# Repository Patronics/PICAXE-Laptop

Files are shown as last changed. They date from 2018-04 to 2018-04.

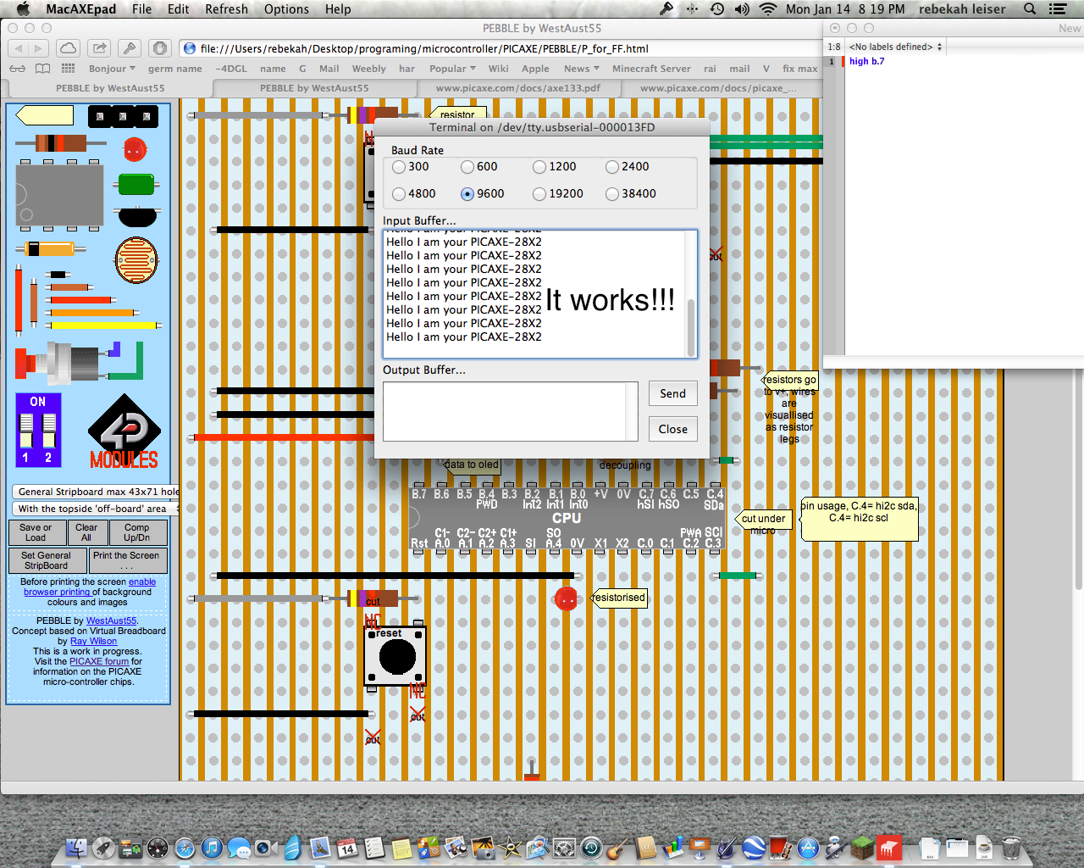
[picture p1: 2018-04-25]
laptop project/report/screenshots/It works!!.png

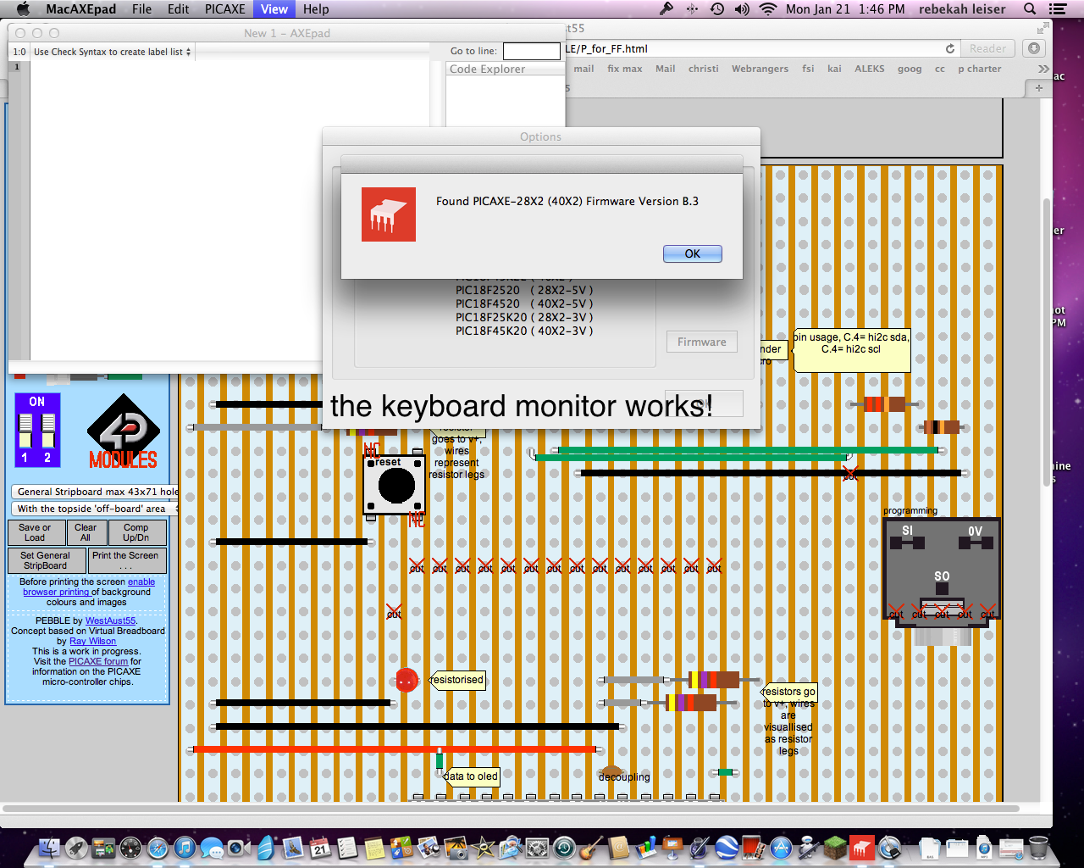
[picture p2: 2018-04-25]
laptop project/report/screenshots/keyboard monitor works!.png

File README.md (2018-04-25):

# PICAXE_Laptop
A PICAXE microcontroller based laptop with a text editor, calculator, timer, and more!

This is a project I made for the Sacramento Regional Science Fair and California State Science Fair in 2013. It won first prize in the regional science fair and 4th in the state science fair.

You can read more about it at my website: http://www.patronics.org/picaxe-computer.html

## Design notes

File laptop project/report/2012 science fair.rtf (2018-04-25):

ideas
Low voltage operating chip "watchdog" to shut down at low voltages (could use low voltage 3 volt 28x2)
later comments: I used calibadc to read the voltage on startup and warn the user if the voltage is too low.
non IBM PC compatible no IBM PC compatible parts (completely original)
hi2cout to enable i²c for keyboard, storage, ect. i2c is an alternative for PCI/PCIe found in most computers. Iimproved efficiency due to using i²c function built into the hardware as opposed doing it with software (bit banging).
light/distance sensor to detect closing of case
switch with transistors to disable all non programming pins (for programming)
use indicator LED's
use multiple slots of 28x2 cpu to have up to four operating systems e.g. sd card; non-sd card functions; one reserved for future use; one for diagnostic purposes.
clear case so people can see internal electronics
organize the files on the computer in a hierarchical file system rather than a sinjgle level file system you may then organize files by their purpose or type e.g. system, data, logs, etc.

Log
12/24/12 worked on basic microcontroller requirements (programming and power)
Setting up hardware hi2c out to enable i2c (for keyboard, storage, etc.)
Planned and added switch to reset pin with resistor. Added pull-up resistor.
12/26 Need SD card reader/writer to improve capacity to potentially allow communication between my laptop and other computers
12/28 Trying to find plain file editor (not plain text)
1/5 reading manual for alfat and card reader board, needs 3.3 volts so will need to have a voltage regulator from 4.5 to 3.3 volts.
later comments: instead of using a voltage regulator I used 3 batteries in series with the contacts of each acsesable I got 3 volts directly for 2 of the batteries for the alfat board.
Since you can't choose and edit any part of a file when you choose a file it will load it into RAM (possible external FRAM and after the edits have been made give options to save the file or discard the changes.
I am using the sd card reader for all data storage so do not need the FRAM.
1/12 soldered connections for power and programming for both CPU and keyboard.
1/14 continued to solder basic connections, then tested followed by debugging for two plus hours. Wrote test program to blink LED from main processor.
1/18 - 2.5 battery case wires broke so replaced with 3 individual AA battery boxes on separate stripboard for increased durability and selectable voltage of 1.5,3, and 4.5 volts. Debugged and successfully fixed (there was a problem with the programming connector) the PICAXE 2.8X2 keyboard processor. Added keyboard connector and successfully got keyboard. I wrote and tested a program allowing the keyboard processor to sent keyboard data to the main processor.
1/20 - 2/1 Constructed case.
2/2 connected screen. Did several tests/demo programs. Display all possible characters on
screen; display characters, number and symbol for character typed on keyboard. Display typed symbols on screen sequentially in text editor fashion. (like Pages, Word, etc.) Changed decoding code to display correct symbols. Entered key identifying function into keyboard controller to free up processsing of CPU
.2/4 decreased code size from 1064 bytes to 832 with optimization of menu structure.
2/7 Added functionality for sleep mode in both CPU and keyboard with keyboard waking up CPU when wake up key pressed on keyboard. Drilled holes on case to allow for external programming while in case.
2/8 Added circuit for sd card reader; successfully interfaced with sd card reader and received its version number through i²c (as a basic test of whether it could read it or not)
2/09 Created filoe hello world.txt, successfully read it from sd card reader; I set sd card reader to read 80 characters (the size of the display) with spaces for any unused characters instead of being the exact number of characters on the document.
2/10 Organized files on in a hierarchical file system rather than a single level file system.
2/11 SD read: the sd read routine reads one page of the file and allows it to create a shortcut from the menu or input it with typing (or any other way I program )instead of having a separate program everytime you need to read a fie.
2/12 The sd writing program occasionally frooze. Set it to Sertxd (send data to computer) to see where a program froze. I identified that the keyboard uc was functioning properly since kb still blinked LED's and when I set main uc to Sertxd the value from the keyboard lead it would return proper value and would not return any value if it was frozen.
I added method to go to any file on the drive with file path. Writing code for ad rad set up. Theoretically I could put any file on it and it would read it.
2/16 When I was debugging

2/18 Added capitalization by programming the keyboard monitor so when shift key is pressed a bit variable called shift is set to equal one and when this variable is set to one the microcontroller reads the value of the key to convert it to the correct character from its internal storage (called EEPROM) and then sets the variable shift to zero. It functions similarly to an iPhone when shift is pressed the next key is capitalized and then goes back touncapitalized. It functions similarly to caplock but toggles the bit each time cap lock is pressed.
2/19 I modified the file listing function to display files in an easy to read format, showing the ``````````````````````file name,it's attributes( e.g. read only, hidden, etc.), and the file's size.
The sd read reoutine reads one page worth of the file ande allows it to create a shortcut from the nmenu or input it with typing (or any other way I program) instead of having a separate program everytime you need to read a file.
I added function to read the power supply voltage (battery level) using the calib adc command and some math. I am now able to read the voltage with 100 milliamp resolution without a multimeter ( no longer need to open case to test batteries).
2/20 added function to check power supply on start up and warn if it was low. Fixed code to remove unnecessary characters from sd card reads. Worked on single character sd card reads allowing for enter, tab, etc.
2/21 Working on making the program execution by over-clocking the frequency to 16 Mhz instead of the default 8 Mhz. Need to change the commands that require specific timing such as pause, hhitc set up, serout. I realized I only have to use some symbol that will be assigned a different value depending on thefrequency defined. I can't set fequency higher though I could use an external resonater pf up to 6hz. Serial communication speed for screen would be too fast. I am not working on this now as the screen seemed to be unable to keep up with the cpu, in the future I will try to overclock the screen so it can keep up.
I added function to save contents of the display when using word edit, when a user presses print screen on the keyboard. Now it is possible to write to the sd card.
2/24 In word edit I added a function to support tab key.

List of supplies:
serial 20x4 OLED display $30.00 (cheap alternative serial LCD: $9.00)
picaxe 28X2 microcontroller (2) $6.80 ea.
plain stripboards (perfboard) (3 - 4) $1.50 ea.
single AA battery holder (3) $1.09 ea.
Alfat SD card reader $44.95
resistors (22k (2), 10k (2), 4.7k (2) negligible ($10.00 for 500 pieces)
various wires (negligible)
ps2 keyboard $5.00
ps2 stripboard adaptor $.95
power switch $1.00
sd card (up to 32 GB) (lower capacity acceptable) $6.95 for 2 GB $15.00 for 16 GB
programming adaptor (headphone jack) $.10

Optional Supplies:
decoupling capacitors(3) (highly recommended) $0.10
ethernet cable/adaptor (communication between top and bottom halves of laptop) (use wires if not using this) ( free sample from molex.com)
indicator LEDs (2) $.09 ea,
case (material of your choice eg. wood/plastic) $10.00 and up
200 ohm resistors (for indicator LEDs) (2) negligible
extension cable (to program without opening case) $0.97

entry level: $89.10
full version: $129.26

Procedure
Ordered componets
Constructed case from plastic sheets and blocks.
Draw a stripboard diagram using PEBBLE (PICAXE Electronic BreadBoard Emulator)
Solder the PICAXE microcontrollers and programming connectors and tested circuit, with program to blink an LED, hardware was not found. After several tests I discovered that the programming connectors made an intermittant connection and needed resoldering.
Solder the data and clock lines of the i²c bus connecting the PICAXE 28 x2 CPU and the 2 x2 keyboard monitor.
Soldered keyboard adaptor, first keyboard didn't work so ordered another as a replacement. The native ps2 keyboard from our old computer works.
Battery cables broke so decided to make a more durable and efficient power supply.

conclusion notes
SD card related operating system functions: read from sd card, read files on sd card, write to sd card,
I have the idea to allow background programs/processes. e.g. timer, etc. by designating some variables for background processing separately from the active program varibles (RAM)

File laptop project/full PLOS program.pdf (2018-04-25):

1 | picaxe laptop demo program slot 0 | 'by Patrick Leiser
2 | #picaxe 28x2
3 | #slot 0
4 | #revision 2
5 | 'pinout
6 | ' | _________
7 | ' | reset | rst B.7 | LED (red)
8 | ' | | A.0 B.6| Speakers
9 | ' | | A.1 B.5|
10 | ' | | A.2 B.4|
11 | ' | | A.3 B.3|
12 | ' | serin |serin B.2| keyboard wakeup (currently unused)
13 | ' | serout |A.4 B.1|
14 | ' | 0V | 0V B.0|
15 | ' | | res +V| +5V
16 | ' | | res 0V | | 0V
17 | ' SD card busy | C.0 C.7|
18 | ' OLED serout | C.1 C.6|
19 | ' | | C.2 C.5|
20 | ' | hi2c | C.3 C.4| hi2c (keyboard and SD card)
21 | ' | _________
22 | #define 8mhz | 'clock frequency is 8mhz
23 | '#define 16mhz | 'too fast for display, overclock display to 32 Mhz?
24 | #ifdef 8mhz
25 | setfreq m8 | 'set clock frequency to 8MHz
26 | symbol screenspeed=N2400_8 | 'N2400 at 8 MHz
27 | symbol i2cspeed=i2cfast_8 | 'i2c 400khz at 8 MHz
28 | #endif
29 | #ifdef 16mhz
30 | setfreq m16 | 'set clock frequency to 16 MHz
31 | symbol screenspeed=N2400_16 | 'N2400 at 16 MHz
32 | symbol i2cspeed=i2cfast_16 | 'i2c 400khz at 16 MHz
33 | #endif
34 | 'i2c constants
35 | symbol alfat=%10100100 | 'sd card reader
36 | symbol keyboard=%01010100 | 'keyboard reading PICAXE 28X2
37 | 'system variables
38 | symbol screenlevel=bit0 | 'unused scrolling function
39 | symbol tempbit1 =bit1 | 'temporary bit 1
40 | symbol tempbit2=bit2 | 'tempoary bit 2
41 | symbol loopcount=b11 | ' number of loops in for...next loops
42 | symbol menupage=b21 | 'which page of menu you are on
43 | 'keyboard variables
44 | symbol keycheck = b4 | 'will be one when data is valid, otherwise 0 or 255
45 | symbol keyraw =b5 | 'data direcly from keyboard
46 | symbol keyascii = b6 | 'data from keyboard converted to ASCII
47 | symbol keynum = b7 | ' value of number keys 0-9
48 | 'wordedit variables
49 | symbol cursorrow = b8 | 'part of row in wordedit
50 | symbol cursorcol = b9 | 'part of colum in wordedit
51 | symbol cursorpos = b10 | 'cursor position for OLED
52 | '
53 | symbol temp1=b14 | 'temporary byte (8 bits)1
54 | symbol temp2=b15 | 'tempoaray byte 2
55 | symbol tempw1=w7 | 'tempoary word (16 bits) 1 (overlaps temp1 and temp2)
56 | symbol temp3=b16 | 'tempoary byte 3
57 | symbol temp4=b17 | 'tempoary byte 4
58 | symbol tempw2=w8 | 'tempoary word 2 | (overlaps temp3 and temp4
59 | symbol temp5=b18 | 'tempoary byte 5
60 | symbol temp6=b19 | 'tempoary byte 6
61 | symbol tempw3=w9 | 'tempoary word 3 | (overlaps temp5 and temp6

62 | symbol charremove=b20 | 'amount of sd card data to remove eg !00
63 | 'symbol charremove1=b24 | 'single character to remove eg !
64 | symbol pointertrack=w11 | 'track pointer read loops
65 | symbol first=b24
66 | symbol second=b25
67 | 'game variables
68 | 'symbol guesscount = b11
69 | 'symbol hitcount = b0
70 | 'symbol gamerandom = b12
71 | 'symbol gamerandom2 =b13
72 | 'symbol gamerandom3 =b14
73 | 'symbol gamerandom4 =b15
74 | 'symbol gamerandom5 =b16
75 | 'symbol gamerandom6 =b17
76 | 'symbol gamerandom7 =b18
77 | 'symbol gamerandom8 =b19
78
79
80 | 'math variables
81 | 'symbol math1=w3 'b4/b5
82 | 'symbol mathone=w3 'b4/b5
83 | 'symbol math2=w4 'b6/b7
84 | 'symbol mathtwo=w4 'b6/b7
85 | 'symbol mathresult=w6'b8/b9
86 | 'startup
87
88
89 | if pinC.4=0 then | ' if i2c read/write in progress
90 | for loopcount = 0 to 15
91 | toggle C.3 | 'clear i2c bus read/write
92 | pause 30
93 | if pinC.4=1 then exit
94 | next loopcount
95 | endif
96 | hi2csetup i2cmaster,alfat,i2cspeed,i2cbyte | 'setup i2c comunication for SD card reader
97 | 'pause 200
98 | hi2cout ("I M:",lf) | 'initalise sd card
99
100 | setup:
101 | hi2cin (b12)
102 | if b12=255 then setup2
103 | if b12 <> "!" then setup
104 | hi2cin (b12,b12,b12)
105
106 | hi2cout ("I M:",lf)
107 | setup2:
108 | #ifdef 8mhz
109 | 'pause 600
110 | tune B.6,4,($40,$42,$44,$45,$47,$02,$49) | 'startup chime
111 | #endif
112 | #ifdef 16mhz
113 | tune B.6,8,($40,$42,$44,$45,$47,$02,$49) | 'startup chime
114 | #endif
115 | serout C.1, screenspeed, (254,128,254,1)'clear display
116
117 | 'read voltage
118 | 'CalibAdc10 tempw1 | 'read voltage of internal fixed voltage reference
119 | gosub getvolts
120 | 'tempw1 = 10476 / tempw1 | 'convert to volts
121 | if tempw1<38 then
122 | gosub powerdisplay

123 | sound B.6, (50,50,100,50)
124 | gosub getakey
125 | endif
126 | #ifdef 8mhz
127 | pause 30 | 'pause 30 ms
128 | #endif
129 | #ifdef 16mhz
130 | pause 70
131 | #endif
132
133 | '''''''''''''''''''''''''''''''''''''''''''''''''''''''''''''''''''''''''''''''''''''''''''''''''''''''''''''''
134 | 'menus
135 | main:
136 | 'clearvar:
137 | 'for bptr=5 to 255
138 | ' | @bptr=0
139 | 'next bptr
140 | menu: | 'main menu
141 | serout C.1,screenspeed, (254,128,254,1) | 'clear display
142 | pause 30
143 | select case menupage 'select page
144 | case 0 'first page
serout C.1,screenspeed, ("1 Utilities",254,192,"2 Tests",254,148,"3 SD card",254,212,"4 favorites ",180) 'menu display

145

146 'serout C.1,N2400,(254,192,"2 Tests") 147
148 | 'serout C.1,N2400,(254,148,"3 SD card")
149 | 'serout C.1,N2400,(254,148,"3 games")
150 | 'serout C.1,N2400, (254,212,"4 favorites ",180)
151 | 'serout C.1,N2400, (254,212,"4 other")
152 | 'serout C.1,N2400,(254,212,"4 calculator")
153 | case 1 '2nd page
154 | serout C.1,screenspeed,("5 other")
155 | else
156 | menupage=0
157 | goto menu
158 | endselect
159 | gosub getakey
branch keynum, (menu,utilitymenu, testmenu,gamemenu,favoritesmenu,othermenu) | 'go to menu item
selected by key on keyboard

160

161 | 'if keynum = 10 then
162 | select case keyraw | 'shortcut keys
163 | case 29 | 'w
164 | goto wordeditsetup
165 | case 45 | 'r
166 | goto sdreadsetup
167 | case 75 | 'l
168 | goto sdinitalizelist
169 | case 33 | 'c
170 | goto calculatorsetup
171 | endselect
172 | 'endif
173 | if keyraw=90 or keyraw= 114 then
174 | inc menupage
175 | elseif keyraw=102 or keyraw=117 then
176 | dec menupage
177 | endif
178 | goto menu
179
180 | utilitymenu: | 'utility menu
181 | serout C.1,screenspeed, (254,128)

serout C.1, screenspeed, (254,1)
pause 30
serout C.1,screenspeed, ("1 Wordedit") serout C.1,N2400,(254,192,"2 calculator") 'serout C.1,N2400,(254,148,"3 ")

'serout C.1,N2400,(254,212,"4 ")

gosub getakey
branch keynum,(menu,wordeditsetup,calculatorsetup)

if keyraw= 118 or keyraw=108 then menu
goto utilitymenu
197 | testmenu: | 'test menu
serout C.1,screenspeed, (254,128)
serout C.1, screenspeed, (254,1)
| pause 30
serout C.1,screenspeed, ("1 list characters")
serout C.1,screenspeed,(254,192,"2 Keyboard to screen") serout C.1,screenspeed,(254,148,"3 read power supply") serout C.1,screenspeed,(254,212,"4 System info") 'serout C.1,N2400, (254,212,"4 SD card read")
'serout C.1,N2400,(254,212,"4 calculator")
| gosub getakey
branch keynum,(menu,listcharacters,keyboardtoscreen,readpower,sysinfo)',gettime)

if keyraw=118 or keyraw=108 then menu
| goto testmenu sdmenu:

gamemenu: 'sd card menu, used to be game menu
| 'run 1
serout C.1,N2400, (254,128,254,1)
select case menupage
| case 0
serout C.1, screenspeed, ("1 read sdcard")
serout C.1, screenspeed, (254,192,"2 about PLOS")
serout C.1, screenspeed, (254,148,"3 add to visitor log") serout C.1, screenspeed, (254,212,"4 view visitor log ",180) 'serout C.1,N2400, ("no games, press esc")
'serout C.1,N2400,(254,192,"- subtraction")
'serout C.1,N2400,(254,148,"* multiplication")
'serout C.1,N2400,(254,212,"/ division")
| case 1
serout C.1, screenspeed, ("5 list sd files") serout C.1, screenspeed, (254,192,"6 tutorial")
| else
menupage=0
goto gamemenu
| endselect gosub getakey branch keynum,

(menu,sdreadsetup,sdaboutsetup,visitorlogappend,visitorlogreadsetup,sdinitalizelist,tutorialsetup) if keyraw =118 or keyraw=108 then menu
if keyraw=90 or keyraw= 114 then
inc menupage
elseif keyraw=102 or keyraw= 117 then

242 | dec menupage
243 | endif
244
245 goto sdmenu
246
247 | favoritesmenu: | 'shortcuts to sd card files ect menu
248 | serout C.1,screenspeed, (254,128,254,1)
249 | pause 30
250 | serout C.1,screenspeed, ("1 ")
251
252 | gosub getakey
253 | branch keynum, (menu)
254
255 | if keyraw = 118 or keyraw =108 then menu
256 | goto favoritesmenu
257
258 | othermenu:
259 | serout C.1,screenspeed, (254,128)
260 | serout C.1, screenspeed, (254,1)
261 | pause 30
262 | serout C.1,screenspeed, ("1 star animation")
263
264 | gosub getakey
265 | branch keynum, (menu,staranimatesetup)
266
267 | if keyraw = 118 or keyraw =108 then menu
268 | goto othermenu
269 | ''''''''''''''''''''''''''''''''''''''''''''''''''''''''''''''''''''''''''''''''''''''''''''''''''''''''''''''
270 | 'sub program 1: wordedit
271 | 'a text editor like pages or word
272 | wordeditsetup:
273 | serout C.1, screenspeed, (254,14,254,128,254,1) 'cursor on, top of display, clear display
274 | pause 30
275 | cursorrow=0 | 'top of display
276 | cursorcol=0 | 'top of display
277 | wordedit:
278 | gosub getakey | 'get a key from keyboard
279
280 | select case keyraw | 'select raw key value
281 | case 118 | 'esc
282 | goto menu
283 | case 108 | 'home
284 | cursorrow=255
285 | cursorcol=0
286 | case 90 | 'enter
287 | cursorrow = 21
288 | case 102 | 'backspace
289 | if cursorrow = 0 then
290 | dec cursorcol
291 | cursorrow = 20
292 | endif
293 | cursorrow=cursorrow-1
294 | gosub position
295 | cursorrow=cursorrow-1
296 | serout C.1,screenspeed, (" ")
297 | case 13 | 'tab
298 | cursorrow=cursorrow+2
299 | serout C.1, screenspeed, (" ")
300 | @bptrinc=9 | 'tab
301 | @ptrinc=9
302 | @bptrinc=0 | 'null

303 | @bptr=0 | 'null
304 | case 107 | 'left arrow
305 | if cursorrow = 0 then
306 | dec cursorcol
307 | cursorrow = 20
308 | endif
309 | cursorrow=cursorrow - 2
310 | case 116 | 'right arrow
311 | case 114 | 'down arrow
312 | inc cursorcol
313 | dec cursorrow
314 | case 117 | 'up arrow
315 | dec cursorcol
316 | dec cursorrow
317 | case 124
318 | serout C.1, screenspeed, (254,128,"print screen")
319 | goto printscreen
320 | else
321 | serout C.1,screenspeed, (keyascii)
322 | @bptr=keyascii | 'store contents of the screen for ability to save
323 | @ptrinc=keyascii | 'store contents of the screen for abbility to save in progress
324 | endselect
325
326 | inc cursorrow
327 | gosub position
328 | goto wordedit
329 | position: | 'update position of cursor
330 | if cursorrow >19 then
331 | inc cursorcol
332 | cursorrow=0
333 | endif
334 | select case cursorcol
335 | case 1
336 | cursorpos=192
337 | 'serout C.1, N2400, (254, 192)
338 | 'serout C.1, N2400, ("ln 1")
339 | case 2
340 | cursorpos=148
341 | 'serout C.1, N2400, (254, 148)
342 | 'serout C.1,N2400,("ln 2")
343 | case 3
344 | cursorpos=212
345 | 'serout C.1,N2400, (254,212)
346 | 'serout C.1, n2400,("ln 4")
347 | else
348 | cursorpos=128
349 | 'serout C.1,N2400,(254,128)
350 | 'serout C.1,N2400,("ln 0")
351 | cursorcol=0
352 | endselect
353 | cursorpos = cursorrow+cursorpos
354 | bptr=cursorpos
355 | serout C.1, screenspeed, (254,cursorpos)
356 | return
357 | goto wordedit
358
359
360 | printscreen: ' save the contents of the screen to SD card
361 | hi2cout [alfat],("O 1A>M:\\screenshots",92) '92=\ | \\=\
362 | serout C.1, screenspeed, (254,128,"name (not full path)")
363 | gosub sdout

364 pointertrack= ptr
365
366 | first = pointertrack / 16 + "0" | '4 msb plus ascii "0"
367 | If first > "9" Then | 'if more than "9"
368 | first = first + 7 | 'add seven (starting "A","B",etc
369 | EndIf
370
371 | second = pointertrack & $0F + "0"
372 | If second > "9" Then
373 | second = second + 7
374 | EndIf
375 | hi2cout ("W 1>",first,second,lf) 'write handle 1, pointertrack characters,
376 | sertxd (#pointertrack)
377 | hi2cin (b12,b12,b12,b12)
378 | for ptr=0 to pointertrack
379
380
381 | hi2cout (@ptr)
382 | sertxd (@ptr,#ptr)
383 | for loopcount = 0 to 14
384 | hi2cin (b12)
385 | next loopcount
386 | next ptr
387 | 'for bptr=128 to 147 | 'line 1
388 | ' | hi2cout ("W 1>1",lf) 'write handle 1, one character,
389 | ' | hi2cin (b12)
390 | ' | serout C.1,screenspeed, (b12)
391 | ' | hi2cin (b12)
392 | ' | serout C.1,screenspeed, (b12)
393 | ' | hi2cin (b12)
394 | ' | serout C.1,screenspeed, (b12)
395 | ' | hi2cin (b12)
396 | ' | serout C.1,screenspeed, (b12)
397 | ' | hi2cout(@bptr)
398 | ' | for loopcount = 0 to 14
399 | ' | hi2cin (b12)
400 | ' | next loopcount
401 | 'next bptr
402 | 'for bptr=192 to 211 | 'line 2
403 | ' | hi2cout ("W 1>1",lf)
404 | ' | hi2cin (b12,b12,b12,b12)
405 | ' | hi2cout(@bptr)
406 | ' | for loopcount = 0 to 14
407 | ' | hi2cin (b12)
408 | ' | next loopcount
409 | 'next bptr
410 | 'for bptr=148 to 167 | 'line 3
411 | ' | hi2cout ("W 1>1",lf)
412 | ' | hi2cin (b12,b12,b12,b12)
413 | ' | hi2cout(@bptr)
414 | ' | for loopcount = 0 to 14
415 | ' | hi2cin (b12)
416 | ' | next loopcount
417 | 'next bptr
418 | 'for bptr=212 to 241 | 'line 4
419 | '' | hi2cout ("W 1>1",lf)
420 | ' | hi2cin (b12,b12,b12,b12)
421 | ' | hi2cout(@bptr)
422 | ' | for loopcount = 0 to 14
423 | ' | hi2cin (b12)
424 | ' | next loopcount

425 'next bptr
426
427 | hi2cout ("C 1",lf)
428 | hi2cout ("C 1",lf)
429 | hi2cin (b12,b12,b12,b12)
430
431 | serout C.1, screenspeed, (254,128,"complete")
432 | gosub getakey
433 | goto wordeditsetup
434 | ''''''''''''''''''''''''''''''''''''''''''''''''''''''''''''''''''''''''''''''''''''''''''''''''''''''''''''''''''''''''''
435 | 'sub program 2: keyboard to screen
436 | keyboardtoscreen: | 'show information about key on screen
437 | gosub getakey 'read a key
438 | serout C.1,screenspeed, (254,128,254,1) 'clear screen
439 | serout C.1,screenspeed, (#keyraw," ",keyascii," ",#keyascii," ",#keynum) 'display information about key
440 | if keyraw = 118 then 'if escape
441 | #ifdef 8mhz
442 | pause 1000 | 'pause a second
443 | #endif
444 | #ifdef 16mhz
445 | pause 2000 | '1 sec
446 | #endif
447 | goto menu | 'go to menu
448 | endif
449 | goto keyboardtoscreen 'loop
450
451 | '''''''''''''''''''''''''''''''''''''''''''''''''''''''''''''''''''''''''''''''''''''''''''''''''''''''''''''''''''''''''''
452 | 'sub program 3: list characters
453 | listcharacters: | 'list caracters avaiable for display
454 | serout C.1,screenspeed,(254,128) ; move to start of first line
455 | for b0 = 0 to 252 | 'all characters, no commands
456 | serout C.1,screenspeed,(b0," ") 'display character and space
457 | inc cursorrow 'next position on display
458 | gosub position
459 | gosub checkforkey 'check if esc has been pressed
460 | if keyraw= 118 then menu
461 | next b0
462
463 goto listcharacters
464
465 | 'gettime: 'unused routine to retrive time
466 | 'serout C.1, screenspeed, (254,128,254,1)
467 | 'pause 30
468 | 'hi2cout ("G D",lf)
469 | 'for loopcount =0 to 11
470 | ' | hi2cin (b12)
471 | ' | serout C.1, screenspeed, (b12)
472 | 'next loopcount
473 | 'serout C.1, screenspeed, (254,192)
474 | 'hi2cout ("G T",lf)
475 | 'for loopcount =0 to 8
476 | ' | hi2cin (b12)
477 | ' | serout C.1, screenspeed, (b12)
478 | 'next loopcount
479 | 'gosub getakey
480 | 'goto menu
481 | 'settime:
482 | 'hi2cout ("T B",lf)
483 | 'hi2cin (b12,b12,b12,b12)
484 | 'pause 200
485 | 'hi2cout ("S 42566DA0",lf)

486 | 'hi2cin (b12,b12,b12,b12)
487 | 'goto menu
488 | '''''''''''''''''''''''''''''''''''''''''''''''''''''''''''''''''''''''''''''''''''''''''''''''''''''''''''''''''''''''''
489 | 'voltage reader
490 | readpower:
491 | serout C.1,screenspeed, (254,128,254,1) 'clear display
492 | pause 30
493 | gosub getvolts
494 | gosub powerdisplay
495 | gosub getakey
496 | goto main
497 | getvolts:
498 | CalibAdc10 tempw1
499 | tempw1 = 10476 / tempw1
500 | bintoascii tempw1,temp3,temp3,temp4 | 'lower byte of temp w1
501 | return
502 | powerdisplay:
503 | 'tempw1 = 52377 /tempw1 * 2
504 | 'serout C.1,screenspeed, (#tempw1)
505 | serout C.1, screenspeed, ("power=",temp3,".",temp4," V")
506 | serout C.1, screenspeed, (254,192,"full charge=4.5 V")
507 | return
508 | 'gosub getakey
509 | 'goto main
510 | '''''''''''''''''''''''''''''''''''''''''''''''''''''''''''''''''''''''''''''''''''''''''''''''''''''''''''''''''''''''
511 | sdaboutsetup:
512 | pause 30
513 | hi2cout [alfat],("O 0R>M:\\system\\about.txt",lf) | '\\= \
514 | goto presdread
515
516 | sdreadsetup: | 'read file at path indicated
517 | serout C.1, screenspeed, (254,1) | 'clear display
518 | pause 30 | 'wait for display to clear
519 | serout C.1, screenspeed, (254,128,"full file path",254,192) | 'prompt user for full file path
520 | hi2cout [alfat],("O 0R>M:",92) | 'open a file in handle 0, read mode with a path starting with M:\
521 | gosub sdout | 'gosub sdout (down two lines)
522 | goto presdread 'goto sdreadsetup2
523 | sdout: 'let the user choose file path
524 | do 'start do loop
525 | gosub getakey | 'get a key
526 | select case keyraw | 'choose the value of raw key value
527 | case 90
528 | exit
529 | case 93 | '\
530 | hi2cout (92) | '\
531 | serout C.1,screenspeed, (218)
532 | case 74, 76,84,91 | ' ilegal characters
533 | case 118 | 'escape or home
534 | hi2cout (lf)
535 | pause 50
536 | hi2cout ("C 0",lf)
537
538 | else
539 | serout C.1, screenspeed, (keyascii)
540 | hi2cout (keyascii)
541 | endselect
542 | loop
543 | hi2cout (lf)
544 | return
545
546 | presdread: | 'setup for read

547 | serout C.1,screenspeed, (254,128,254,1) 'clear screen
548 | pause 30 'wait for display to clear
549 | cursorrow=0 'first character of screen
550 | cursorpos=0 'top of screen
551 | gosub position 'update position
552 | sdread: | 'read SD card
553 | 'inc tempw3
554 | 'sertxd (" ",#tempw3," ")
555 | 'bug: read stops after 125th character.
556 | 'cursorrow=0
557 | 'gosub position
558 | 'hi2cin (b12,b12,b12)
559 | hi2cout ("R 0",23,">1",lf) | 'read one byte of file | '23=end of transmit block in ASCII
560 | 'serout C.1, N2400, (254,128,254,1) 'go to first line
561 | 'pause 30
562 | 'sertxd ("R")
563 | charactercutoff: | 'cutoff error/sucess codes
564 | do
565 | hi2cin(b12) | 'read a byte
566 | loop until b12="!" | 'loop until end of error codes
567 | 'sertxd ("1")
568 | 'if loopcount >= 4 then
569 | loopcount=loopcount+1 max 5
570 | 'goto charactercutoff
571 | if loopcount < 4 then charactercutoff 'loop four times
572 | 'endif
573 | if charremove>0 then 'if charremove is more than 0 loop that many times
574 | dec charremove
575 | 'sertxd ("2")
576 | goto charactercutoff
577 | 'if tempbit1=1 then
578 | ' | tempbit1=0
579 | ' | goto charactercutoff
580 | endif
581 | 'if tempbit1=0 then
582 | ' | hi2cin (b12)
583 | ' | tempbit1=1
584 | 'endif
585 | hi2cin (b12,b12,b12)',b12,b12)',b12)
586 | 'sertxd ("L")
587 | 'if tempbit2=0 then
588 | ' | hi2cin (b12)
589 | ' | tempbit2=1
590 | 'endif
591 | 'serout C.1, N2400, (254,128) | 'output to display
592 | 'cursorrow=0
593 | 'cursorcol=0
594 | 'gosub position
595 | do
596 | hi2cin (b12)
597 | select case b12
598 | case"$"
599 | exit
600 | case lf,cr | 'enter
601 | cursorrow=0
602 | inc cursorcol
603 | if cursorcol >=4 then sdreadpageend | 'end of page
604 | case 23 | 'end of transmision
605 | gosub getakey | 'wait for keypress
606 | hi2cout ("C 0",lf) | 'close handle
607 | goto menu | 'goto menu

608 | case 9
609 | cursorrow=cursorrow+3
610 | case 7 | 'bell
611 | ' bell tone
612 | tune B.6,8,($02,$07)
613 | case <31
614 | endselect
615 | gosub position
616 | serout C.1, screenspeed, (b12)
617 | 'elseif b12=10 then | 'enter
618 | ' | inc cursorcol
619 | ' | cursorrow=0
620 | ' | gosub position
621 | 'if b12 <> "$" then
622 | 'endif
623 | loop
624 | charremove=1
625
626 | inc cursorrow
627 | if cursorrow>=20 and cursorcol >=3 then sdreadpageend | 'end of page
628 | if cursorcol >= 4 then sdreadpageend | 'end of page
629 | gosub position
630 | 'hi2cin (b12,b12,b12,b12)
631 | goto sdread
632 | sdreadpageend: | 'end of page
633 | do
634 | gosub getakey
635 | if keyraw=90 then | 'if key is enter then
636 | tempbit1=1
637 | 'charremove=charremove+1
638 | tempbit2=1
639 | cursorrow = 0 'top of display
640 | cursorcol = 0 'top of display
641 | gosub position ' update position
642 | goto presdread | 'goto next page
643 | elseif keyraw=125 then
644 | hi2cout ("P 0>0",lf)
645 | goto presdread
646 | 'elseif keynum<10 then
647 | 'keynum=keynum*50
648 | 'gosub pageselect
649 | ' | hi2cout ("P 0>",#b7,lf)
650 | ' | tempbit1=1
651 | 'charremove=1
652 | 'tempbit2=1
653 | ' | goto presdread
654 | elseif keyraw=118 then | 'escape or
655 | hi2cout ("C 0",lf)
656 | hi2cin (b12,b12,b12,b12)
657 | 'for loopcount= 0 to 17
658 | 'hi2cin (b12)
659 | 'next loopcount
660 | goto menu
661 | endif
662 | loop
663
664
665 | visitorlogappend: | 'add to visitor log
666 | serout C.1, screenspeed,(254,1) | 'clear screen
667 | pause 30'wait for screen to clear
668 | do

669 | ' | pause 100
670 | loop until pinC.0=0 | 'wait for buisy pin to go low
671 | hi2cout [alfat],("O 1A>M:\\data\\visitor log.txt",lf)'open M:data\visitor log.txt in write mode file handle 1
672 | hi2cin (b12,b12,b12,b12) 'read error code
673 | serout C.1, screenspeed, (254,128,"initials?") 'prompt user for initials
674 | gosub getakey | 'get a key
675 | serout C.1, screenspeed,(254,148,keyascii,".") | 'display key
676 | b13=keyascii | 'store data in b13
677 | gosub getakey | 'get a key
678 | serout C.1, screenspeed,(keyascii,".") 'display key
679 | do
680 | 'pause 100
681 | loop until pinC.0=0 | 'wait until busy bin is low
682 | hi2cout ("W 1>5",lf) | 'write handle 1, five characters
683 | 'pause 10
684 | for loopcount=0 to 19 | 'repeat 20 times
685 | hi2cin (b12) | 'read a character
686 | serout C.1, screenspeed, (b12) | 'output to screen
687 | inc cursorrow 'move cursor
688 | gosub position | 'update cursor position
689 | next loopcount
690 | 'pause 1000
691 | hi2cout (b13,".",keyascii,". ") | 'write initials to SD card
692 | serout C.1,screenspeed, (254,192) | 'begining of display
693 | 'pause 1000
694 | hi2cout ("C 1",lf) | 'close file handle
695 | pause 100
696 | for loopcount=0 to 26 | 'repeat 27 times
697 | hi2cin (b12) | 'read character
698 | serout C.1, screenspeed, (b12) | 'output to display
699 | 'sertxd("3")
700 | next loopcount 'repeat
701 | serout C.1, screenspeed, ("complete") | 'output to display "complete"
702 | pause 1000 'pause a second
703 | 'toggle b.7
704 | goto menu 'goto main menu
705
706
707 | visitorlogreadsetup: | 'read visitor log
708 | 'pause 30
hi2cout [alfat],("O 0R>M:\\data\\visitor log.txt",lf) | 'open file on handle 0, read mode, path M:\data\visitor
log.txt

709

710 | 'pause 500
711 | goto presdread 'setup for sd card read
712
713 | tutorialsetup: 'read tutorial
714 | 'pause 30
| hi2cout [alfat],("O 0R>M:\\system\\tutorial.txt",lf) 'open handle 0, read mode, file path
| M:\system\tutorial.txt

715

716 | 'pause 500
717 | goto presdread 'setup for sd card read
718
719 | sdinitalizelist: | 'initalize list of files
720 | serout C.1, screenspeed, (254,128,254,1) | ' top of display, clear display
721 | temp1=0
722 | ptr=0
723 | loopcount=0
724 | tempbit1=0
725 | pause 30
726 | cursorrow=0
727 | cursorcol=0

728 | hi2cout [alfat],("@ M:",92)
729 | hi2cin (b12,b12,b12)
730 | serout C.1, screenspeed, ("file path:",254,192)
731 | gosub sdout
732 | serout C.1, screenspeed, (254,148,"press any key for",254,212,"manual mode")
733 | for loopcount=0 to 3
734 | pause 500
735 | gosub checkforkey
736 | if keyraw<> 0 then 'if key is pressed
737 | tempbit1=1
738 | exit
739 | next loopcount
740 | endif
741 | listfiles:
742 | serout C.1, screenspeed, (254,1) 'clear display
743 | cursorrow=0
744 | cursorcol=0
745 | gosub position
746 | hi2cout ("N",lf)
747 | hi2cin (b12,b12,loopcount)
748 | if b12="0" and loopcount="4" then 'if end of menu
749 | hi2cin (b12)
750 | goto menu
751 | endif
752 | loopcount=0
753 | hi2cin (b12)
754 | do
755 | hi2cin (b12)
756 | if b12= lf then 'next data field
757 | inc cursorcol
758 | cursorrow=0
759 | inc loopcount
760
761 | endif
762 | 'if loopcount >1 then' and loopcount <4 then
763 | if b12<> "!" then | 'if not end of command
764 | serout C.1, screenspeed, (b12) | 'output to display data recived
765 | if cursorcol=0 then
766 | @ptr=b12'inc=b12
767 | sertxd (@ptrinc)
768 | endif
769 | inc cursorrow
770 | gosub position
771 | else
772 | hi2cin (b12,b12,b12)
773 | cursorrow=0
774 | cursorcol=0
775 | gosub position
776 | if tempbit1=0 then 'if automatic mode
777 | #ifdef 8mhz
778 | pause 1000 'pause 1 second
779 | #endif
780 | #ifdef 16mhz
781 | pause 2000 '1000 at 16 mhz
782 | #endif
783 | gosub checkforkey
784 | if keyraw=90 then | 'enter
785 | ptr=0
786 | hi2cout [alfat],("O 0R>M:",92) | 'open a file in handle 0, read mode with a path starting with M:\
787 | do
788 | if @ptr=0 then

789 | | exit
790 | | endif
791 | | hi2cout (@ptrinc)
792 | | loop
793 | | hi2cout (lf)
794 | | goto presdread
795 | endif
796 | if keyraw=118 then menu
797 | | goto listfiles
798 | | endif
799 | | gosub getakey
800 | | if keyraw=90 then | 'enter
801 | | ptr=0
802 | hi2cout [alfat],("O 0R>M:",92) | 'open a file in handle 0, read mode with a path starting with M:\
803 | | do
804 | | if @ptr=0 then
805 | | exit
806 | | endif
807 | | sertxd (@ptr)
808 | | hi2cout (@ptrinc)
809 | | loop
810 | | hi2cout (lf)
811 | | goto presdread
812 | endif
813 | if keyraw= 118 then menu
814 | | 'pause 1000
815 | | 'sertxd ("@")
816 | | goto listfiles
817 | endif
818 | if loopcount=4 then
819 | | exit
820 | endif
821 | loop
822 | gosub getakey
823
824
825 | if keyraw= 118 then menu 'if esc goto menu
826 | 'sertxd ("!")
827 | goto listfiles 'repeat
828
829 | ''''''''''''''''''''''''''''''''''''''''''''''''''''''''''''''''''''''''''''''''''''''''''''''''''''''''
830 | 'calculator
831 | calculatorsetup:
832 | tempw1=0 'clear variables
833 | tempw2=0 'clear variables
834 | serout C.1, screenspeed, (254,128,254,14,254,1) 'top of display, cursor on, clear display
835 | pause 30
836 | calculatoroperand1:
837 | gosub getakey 'get a key
838 | if keynum>= 10 and keyraw<> 90 and keyraw<>118 then 'not number, not enter, not escape
839 | 'serout C.1,screenspeed, ("other")
840 | | goto calculatoroperand1
841
842 | elseif keyraw= 118 then | 'esc
843 | | goto menu
844 | elseif keyraw= 90 then | 'enter
845 | goto calculatoroperator 'select operator (*+/- ect)
846 | 'elseif keyraw=102 then | 'backspace
847 | ' | tempw1=tempw1/10 | 'remove character
848 | ' | serout C.1,screenspeed, (254,128,#tempw1," ")
849 | ' | goto calculatoroperand1

850 | else
851 | tempw1=tempw1*10 | 'shift left allowing for another digit
852 | tempw1=tempw1+keynum | 'add new digit
853 | serout C.1, screenspeed, (254,128,#tempw1) | 'display first operand
854 | goto calculatoroperand1 | 'recive next digit
855 | endif
856 | calculatoroperator: | 'select operator (+-*/ ect)
857 | serout C.1, screenspeed, (254,192)', "op")
858 | gosub getakey
859 | select case keyraw
860 | case 85 '+ | add
861 | temp5=0
862 | serout C.1,screenspeed, ("+")
863 | case 78 '-
864 | temp5=1
865 | serout C.1,screenspeed, ("-")
866 | case 62 '* multiply
867 | temp5=2
868 | serout C.1,screenspeed, ("*")
869 | case 74 | '/ divide
870 | temp5=3
871 | serout C.1,screenspeed, ("/")
872 | case 54 | '^ square root
873 | temp5=4
874 | serout C.1,screenspeed, ("square root")
875 | goto calculate | 'unary operator, skip reciving second value
876 | case 45 | 'r random
877 | temp5=5
878 | goto calculate
879 | case 118 | 'esc
880 | goto menu
881 | else
882 | goto calculatoroperator
883 | endselect
884 | calculatoroperand2:
885 | serout C.1,screenspeed, (254,148)
886 | gosub getakey
887 | if keynum>= 10 and keyraw<> 90 and keyraw<>118 then 'not number, not enter
888 | goto calculatoroperand2
889 | elseif keyraw= 118 then
890 | goto menu
891 | elseif keyraw= 90 then
892 | 'serout C.1, screenspeed, ("enter")
893 | goto calculate
894 | 'elseif keyraw=102 then
895 | ' | tempw2=tempw2/10
896 | ' | serout C.1,screenspeed, (254,148,#tempw2," ")
897 | ' | goto calculatoroperand2
898 | else
899 | tempw2=tempw2*10
900 | tempw2=tempw2+keynum
901 | serout C.1, screenspeed, (254,148,#tempw2)
902 | goto calculatoroperand2
903 | endif
904 | goto calculatoroperand2
905 | calculate:
906 | select case temp5
907 | case 0
908 | let tempw1=tempw1+tempw2
909 | ' | serout C.1,screenspeed, ("+")
910 | case 1

911 | let tempw1=tempw1-tempw2
912 | ' | serout C.1,screenspeed, ("-")
913 | case 2
914 | let tempw1=tempw1*tempw2
915 | ' | serout C.1,screenspeed, ("*")
916 | case 3
917 | let tempw1=tempw1/tempw2
918 | ' | serout C.1,screenspeed, ("/")
919 | case 4
920 | let tempw1= SQR tempw1
921 | case 5
922 | if tempw1=0 then
923 | touch16 0, temp1
924 | touch16 0, temp2
925 | endif
926 | random tempw1
927 | 'else
928 | ' | serout C.1, screenspeed, ("error")
929 | endselect
930 | serout C.1,screenspeed, (254,212,#tempw1)',254,192,#tempw1)
931 | do
932 | gosub getakey
933 | if keyraw=90 then
934 | serout C.1, screenspeed, (254,1)
935 | pause 30
936 | serout C.1, screenspeed, (254,128,#tempw1)
937 | tempw2=0
938 | goto calculatoroperator
939 | elseif keyraw=118 then
940 | goto menu
941 | elseif keyraw=102 then
942 | goto calculatorsetup
943 | endif
944 | loop
945
946
947 | 'guesslocation: | 'inefficeint and complicated, may come back to later
948 | ' | serout C.1, N2400, (254,14,254,128)
949 | ' | gosub getakey
950
951 | ' | readadc 17,gamerandom
952 | ' | readadc 17,gamerandom2
953 | ' | readadc 17,gamerandom3
954 | ' | readadc 17,gamerandom4
955
956 | 'guesslocation1:
957 | ' | random gamerandom
958 | ' | serout C.1, N2400, ("1")
959 | ' | select case gamerandom
960 | ' | case <128
961 | ' | goto guesslocation1
962 | 'case <168
963 | ' | goto guesslocation2
964 | ' | case <192
965 | ' | goto guesslocation1
966 | ' | case <232
967 | ' | goto guesslocation2
968 | ' | else
969 | ' | goto guesslocation1
970 | 'endselect
971

972 | 'guesslocation2:
973 | ' | random gamerandom2
974 | ' | serout C.1, N2400, ("2")
975 | ' | select case gamerandom2
976 | ' | case <148
977 | ' | goto guesslocation2
978 | ' | case <168
979 | ' | goto guesslocation3
980 | ' | case <192
981 | ' | goto guesslocation2
982 | ' | case <232
983 | ' | goto guesslocation3
984 | ' | else
985 | ' | goto guesslocation2
986 | ' | endselect
987 | '
988 | 'guesslocation3:
989 | ' | random gamerandom3
990 | ' | serout C.1, N2400, ("3")
991 | ' | select case gamerandom3
992 | ' | case <148
993 | ' | goto guesslocation3
994 | ' | case <168
995 | ' | goto guesslocation4
996 | ' | case <192
997 | ' | goto guesslocation3
998 | ' | case <232
999 | ' | goto guesslocation4
1000 | ' | else
1001 | ' | goto guesslocation3
1002 | ' | endselect
1003 | '
1004 | 'guesslocation4:
1005 | ' | random gamerandom4
1006 | ' | serout C.1, N2400, ("4")
1007 | ' | select case gamerandom4
1008 | ' | case <148
1009 | ' | goto guesslocation4
1010 | ' | case <168
1011 | ' | goto guesslocationplay
1012 | ' | case <192
1013 | ' | goto guesslocation4
1014 | ' | case <232
1015 | ' | goto guesslocationplay
1016 | ' | else
1017 | ' | goto guesslocation4
1018 | ' | endselect
1019
1020 | 'guesslocationplay:
1021 | ' | if hitcount= 15 then
1022 | '' | serout C.1,N2400,(254,128,"You win!",254,192,"it took ",#guesscount,"guesses")
1023 | ' | goto gamemenu
1024 | ' | endif
1025 | ' | gosub getakey
1026 | ' | select case keyraw
1027 | ' | case 118 | 'esc or home
1028 | ' | serout C.1, N2400, (254,1)
1029 | ' | pause 30
1030 | ' | goto gamemenu
1031 | ' | case 90 | 'enter
1032 | ' | goto locationcheck

1033 | ' | case 107 | 'left arrow
1034 | ' | if cursorrow = 0 then
1035 | ' | dec cursorcol
1036 | ' | cursorrow = 20
1037 | ' | endif
1038 | ' | cursorrow=cursorrow - 1
1039 | ' | case 116 | 'right arrow
1040 | ' | inc cursorrow
1041 | ' | case 114 | 'down arrow
1042 | ' | inc cursorcol
1043 | ' | 'dec cursorrow
1044 | ' | case 117 | 'up arrow
1045 | ' | dec cursorcol
1046 | ' | 'dec cursorrow
1047 | ' | endselect
1048 | ' | gosub position
1049 | ' | inc guesscount
1050 | ' | goto guesslocationplay
1051 | '
1052 | 'locationcheck:
1053 | ' | gosub position
1054 | ' | select case cursorpos
1055 | ' | case gamerandom
1056 | ' | | serout C.1, N2400, ("X")
1057 | ' | bit8=1
1058 | ' | | goto guesslocationplay
1059 | ' | case gamerandom2
1060 | ' | | serout C.1, N2400, ("X")
1061 | ' | bit9=1
1062 | ' | | goto guesslocationplay
1063 | ' | case gamerandom3
1064 | ' | | serout C.1, N2400, ("X")
1065 | '' | bit10=1
1066 | ' | | goto guesslocationplay
1067 | ' | case gamerandom4
1068 | ' | | serout C.1, N2400, ("X")
1069 | ' | bit11=1
1070 | ' | | goto guesslocationplay
1071 | ' | else
1072 | ' | | serout C.1, N2400, ("O")
1073 | ' | inc cursorrow
1074 | ' | | goto guesslocationplay
1075 | ' | endselect
1076 | ' | goto guesslocationplay
1077
1078 | ''''''''''''''''''''''''''''''''''''''''''''''''''''''''''''''''''''''''''''''''''''''''''''''''''''''''''''''''''''''
1079 | sysinfo: | 'system info
1080 | serout C.1, screenspeed, (254,128,254,1)
1081 | pause 30
1082 | readrevision temp1
1083 | serout C.1, screenspeed, ("Revision #",#temp1)
1084 | readfirmware temp1
1085 | serout C.1, screenspeed, (254,192,"Firmware #",#temp1)
1086 | readsilicon temp1
1087 | serout C.1, screenspeed, (254,148,"Silicon #",#temp1)
1088 | 'readinternaltemp IT_4V5, 0 ,temp1 | 'M2 only, not X2
1089 | 'serout C.1, screenspeed, (254,148,"CPU temp",#temp1)
1090 | gosub getakey
1091 | goto menu
1092 | '''''''''''''''''''''''''''''''''''''''''''''''''''''''''''''''''''''''''''''''''''''''''''''''''''''''''''''''''''''''''''
1093 | staranimatesetup: | 'star animation

1094 | serout C.1, screenspeed, (254,14) 'turn on cursor
1095 | 'staranimate:
1096 | do
1097 | serout C.1, screenspeed, (" ")
1098 | inc cursorrow
1099 | gosub position
1100 | gosub checkforkey
1101 | if keyraw = 118 then
1102 | exit
1103 | endif
1104 | loop
1105 | goto menu
1106 | ''''''''''''''''''''''''''''''''''''''''''''''''''''''''''''''''''''''''''''''''''''''''''''''''''''''''''''''''''''''''
1107 | #rem | 'inefficient and complicated, may come back to later
1108 | calculatormenu:
1109 | serout C.1,N2400, (254,128)
1110 | serout C.1, N2400, (254,1)
1111 | pause 30
1112 | serout C.1,N2400, ("+ addition")
1113 | serout C.1,N2400,(254,192,"- subtraction")
1114 | serout C.1,N2400,(254,148,"* multiplication")
1115 | serout C.1,N2400,(254,212,"/ division")
1116 | gosub getakey
1117 | select case keyraw
1118 | case 121 | '+
1119 | serout C.1, N2400, (254,1)
1120 | pause 30
1121 | goto add
1122 | case 123 | '-
1123 | serout C.1, N2400, (254,1)
1124 | pause 30
1125 | goto subtract
1126 | case 124 | '*
1127 | serout C.1, N2400, (254,1)
1128 | pause 30
1129 | goto multiply
1130 | case 74
1131 | serout C.1, N2400, (254,1)
1132 | pause 30
1133 | goto divide
1134 | case 118
1135 | goto menu
1136 | else
1137 | goto calculatormenu
1138 | endselect
1139 | add:
1140 | gosub getakey
1141 | | if math1<6500 then
1142 | | math1=math1*10
1143 | | select case keyraw
1144 | case 22
1145 | | math1=math1+1
1146 | case 30
1147 | | math1=math1+2
1148 | case 38
1149 | | math1=math1+3
1150 | case 37
1151 | | math1=math1+4
1152 | case 46
1153 | | math1=math1+5
1154 | case 54

1155 | math1=math1+6
1156 | case 61
1157 | math1=math1+7
1158 | case 62
1159 | math1=math1+8
1160 | case 70
1161 | math1=math1+9
1162 | case 69
1163 | endselect
1164 | else goto add
1165 | endif
1166
1167 | subtract:
1168 | multiply:
1169 | divide:
1170 | goto calculatormenu
1171 | #endrem
1172
1173 | ''''''''''''''''''''''''''''''''''''''''''''''''''''''''''''''''''''''''''''''''''''''''''''''''''''''''''''''''''''''''''''
1174 | checkforkey: | 'check for a key, return even if no key pressed
1175 | 'hi2csetup i2cmaster,%01010100,i2cfast,i2cbyte 'setup i2c master with keyboard slave
1176 | hi2cin [keyboard],0,(keycheck,keyraw,keyascii,keynum)
1177
1178 | if keycheck<>1 then
1179 | keyraw=0
1180 | keyascii=0
1181 | keynum= 10
1182 | else
1183 | hi2cout 0,(2)
1184 | endif
1185
1186 | hi2csetup i2cmaster, alfat, i2cspeed, i2cbyte
1187 | return
1188 | ''''''''''''''''''''''''''''''''''''''''''''''''''''''''''''''''''''''''''''''''''''''''''''''''''''''''''''''''''''''''''
1189 | getakey: | 'key detecting subroutine
1190 | 'hi2csetup i2cmaster,%01010100,i2cfast,i2cbyte 'setup i2c master with keyboard slave
1191 | ' | sertxd("&")
hi2cin [keyboard],0,(keycheck,keyraw,keyascii,keynum) 'get keyboard data formatted by keyboard processor

1192

1193 | 'sertxd(#b23,",",#b24,cr,lf)
1194 | if keycheck<> 1 then 'if ready byte is not equal to 1
1195 | 'keyraw = 0
1196 | ' | sertxd ("#",#keycheck)
1197 | pause 70 'pause 70 ms
1198 | goto getakey | 'loop
1199 | else
1200 | 'sertxd ("got a key")
1201 | ' | sertxd("+")
1202 | hi2cout 0,(2) 'reset keyboard status byte
1203 | endif
1204 | ' | if keynum=11 then powersaversetup
1205 | 'sertxd( "$")
1206 | hi2csetup i2cmaster, alfat, i2cspeed, i2cbyte | 'setup i2c for SD card reader
1207 | 'sertxd("-")
1208 | return | 'return to subroutine call
1209 | ''''''''''''''''''''''''''''''''''''''''''''''''''''''''''''''''''''''''''''''''''''''''''''''''''''''''''''''''''''''''''''
1210 | 'go to power saving mode
1211 | 'powersaversetup: | 'unused power saving routine
1212 | 'gosub scrollright
1213 | 'powersaver:
1214 | 'serout C.1, screenspeed, ("sleeping")

1215 | 'hintsetup %01000100
1216 | 'sleep 14 | '65535 =~38 hours
1217 | 'high b.7
1218 | 'pause 250
1219 | 'low b.7
1220 | 'if pinB.2=0 then powersaver
1221 | 'serout C.1,screenspeed,("awake")
1222 | 'pause 100
1223 | 'gosub scrollleft
1224 | 'return
1225 | '''''''''''''''''''''''''''''''''''''''''''''''''''''''''''''''''''''''''''''''''''''''''''''''''''''''''''''''''''''''''''
1226 | 'scrollright: | 'unused scrolling routines
1227 | 'if screenlevel=0 then
1228 | 'for loopcount=0 to 19
1229 | ' | serout C.1,screenspeed,(254,24,254,168)
1230 | 'next loopcount
1231 | 'screenlevel=1
1232 | 'endif
1233 | 'return
1234
1235 | 'scrollleft: | 'unused scrolling routine
1236 | 'if screenlevel=1 then
1237 | 'for loopcount=0 to 19
1238 | ' | serout C.1,screenspeed,(254,28)
1239 | 'next loopcount
1240 | 'screenlevel=0
1241 | 'endif
1242 | 'return
1243
1244 | '''''''''''''''''''''''''''''''''''''''''''''''''''''''''''''''''''''''''''''''''''''''''''''''''''''''''''''''''''''
1245 | 'pageselect: | 'unused sd card page selecting routine
1246 | 'select case keynum
1247 | 'case 0
1248 | ' | temp1="0"
1249 | ' | temp2="0"
1250 | ' | 'temp3="0"
1251 | 'case 1
1252 | ' | temp1="0"
1253 | ' | temp2="5"
1254 | ' | 'temp3="0"
1255 | 'case 2
1256 | ' | temp1="0"
1257 | ' | temp2="A"
1258 | ' | 'temp3="0"
1259 | 'case 3
1260 | ' | temp1="0"
1261 | ' | temp2="F"
1262 | ' | 'temp3="0"
1263 | 'case 4
1264 | ' | temp1="1"
1265 | ' | temp2="4"
1266 | ' | 'temp3="0"
1267 | ''case 5
1268 | ' | temp1="1"
1269 | ' | temp2="9"
1270 | ' | 'temp3="0"
1271 | 'case 6
1272 | ' | temp1="1"
1273 | ' | temp2="E"
1274 | ' | 'temp3="0"
1275 | 'case 7

1276 | ' | temp1="2"
1277 | ' | temp2="3"
1278 | ' | 'temp3="0"
1279 | 'case 8
1280 | ' | temp1="2"
1281 | ' | temp2="8"
1282 | ' | 'temp3="0"
1283 | 'case 9
1284 | ' | temp1="2"
1285 | ' | temp2="D"
1286 | 'temp3="0"
1287 | 'endselect
1288 | 'return
1289 | #ifdef 8mhz
1290 | #ifdef 16mhz
1291 | #error "both 8 and 16 mhz defined" | 'if both clock frequencys defined create error message
1292 | #endif
1293 | #endif
1294
1295 | #ifndef 8mhz
1296 | #ifndef 16mhz
1297 | #error "frequency not defined" | 'if neither clock frequency defined create error message
1298 | #endif
1299 | #endif
1300
1301
1302
1303
1304
1305
1306
1307
1308
1309
1310
1311
1312
1313
1314
1315
1316
1317
1318
1319
1320
1321
1322
1323
1324
1325
1326
1327
1328
1329
1330
1331
1332
1333
1334
1335
1336

1337
1338
1339
1340
1341
1342
1343
1344
1345
1346
1347
1348
1349
1350
1351
1352
1353
1354
1355
1356
1357
1358
1359
1360 | 'keyboard.bas keyboard monitering program for PLOS laptop | by Patrick Leiser
1361 | #picaxe 28x2
1362 | symbol shift=bit0
1363 | symbol caps=bit1
1364 | symbol keyraw=b5
1365 | symbol keycheck=b1
1366 | symbol keyascii=b2
1367 | symbol keynum=b3
1368 | symbol powerstate=b4
1369 | symbol repeatkey=b6
1370 | symbol loopcount=w4
1371 | EEPROM $00,("?9?5312C?A864?~?") | ' Function keys
1372 | EEPROM $10,("?????Q!???ZSAW@?") | ' Main keyboard keys
1373 | EEPROM $20,("?CXDE$#?? VFTR%?")
1374 | EEPROM $30,("?NBHGY^???MJU&*?")
1375 | EEPROM $40,("?<KIO)(??>?L:P_?")
1376 | EEPROM $50,("??",34,"?{+????",181,"}?|?") '"??'?[=?????]???") | '\\=\ 34="
1377 | EEPROM $60,("?",218,"????",127,"??1?",127,"7???") | ' Numeric keypad keys
1378 | EEPROM $70,("0.",180,"5",126,179,"??B+3-*9??")' | * = print screen
1379 | TABLE $00,("?9?5312C?a864?'?") | ' Function keys
1380 | TABLE $10,("?????q1???zsaw2?") | ' Main keyboard keys
1381 | TABLE $20,("?cxde43?? vftr5?")
1382 | TABLE $30,("?nbhgy6???mju78?")
1383 | TABLE $40,("?,kio09??./l;p-?")
1384 | TABLE $50,("??'?[=????",181,"]?",92,"?") '"??'?[=?????]???") | '\\=\
1385 | TABLE $60,("?",218,"????",127,"??1?",127,"7???") | ' Numeric keypad keys
1386 | TABLE $70,("0.",180,"5",126,179,"??B+3-*9??")
1387 | startup:
1388 | 'setfreq m8
1389 | put 0,0
1390 | hi2csetup i2cslave,%01010100
1391 | pause 500
1392 | 'kbled %10000101 | 'disable LED blinking (enable capslock and scroll lock, disable numlock)
1393 | kbled $80
1394 | main:
1395 | ' | pause 100
1396 | 'sertxd("getting key ")
1397 | kbin keyraw | 'grab one character

1398 | gotkey:
1399 | if keyraw=128 then | 'print screen (tries to capitalise instead without this)
1400 | elseif keyraw=18 or keyraw=89 then
1401 | | shift=1
1402 | | goto main
1403 | elseif keyraw = 88 then
1404 | | inc caps
1405 | | goto main
1406 | endif
1407 | 'sertxd("got key ")
1408 | 'sertxd(#b0)
1409 | 'sertxd(cr)
1410 | get 0,b1
1411 | 'if b1=1 then main | 'if status=ready, discard character
1412
1413 | put 1,keyraw | 'if status <> ready, store character
1414 | if caps=1 or shift=1 then
1415 | read keyraw,b2 | 'read eeprom for capitalised ascii
1416 | shift=0
1417 | else
1418 | readtable keyraw,b2
1419 | endif
1420 | put 2,b2
1421 | select case keyraw | 'numbers or significant commands
1422 | case 69
1423 | | b3=0
1424 | case 22
1425 | | b3=1
1426 | case 30
1427 | | b3=2
1428 | case 38
1429 | | b3=3
1430 | case 37
1431 | | b3=4
1432 | case 46
1433 | | b3=5
1434 | case 54
1435 | | b3=6
1436 | case 61
1437 | | b3=7
1438 | case 6
1439 | | b3=8
1440 | case 70
1441 | | b3=9
1442 | 'case 63 | 'sleep button
1443 | ' | powerstate=1
1444 | ' | b3=11 | 'sleep command on master
1445 | 'case 94 | 'wake up button
1446 | ' | high A.3
1447 | ' | powerstate=0
1448 | ' | b3=12
1449 | ' | pause 500
1450 | ' | low A.3
1451 | else
1452 | | b3=10
1453 | endselect
1454 | put 3,b3
1455 | put 0,1 | 'update status=ready
1456 | 'pause 400
1457 | do
1458 | get 0,keycheck 'b1

1459 | loop until keycheck=2
1460 | 'debug
1461 | 'goto main
1462
1463
1464 | repeatcheck: | 'prevent repeats if key is held too long
1465 | kbin [450,norepeat], repeatkey
1466 | 'sertxd ("1")
1467 | if repeatkey=keyraw then
1468 | inc loopcount
1469 | if loopcount>10 then
1470 | loopcount=0
1471 | goto main
1472 | endif
1473 | goto repeatcheck
1474 | else'if repeatkey <> keyraw then
1475 | keyraw=repeatkey
1476 | repeatkey=0
1477 | goto gotkey
1478 | endif
1479 | goto main
1480 | norepeat:
1481 | repeatkey=0
1482 | goto main
1483
1484
1485
1486
1487
1488
1489
1490
1491
1492
1493
1494
1495
1496
1497
1498
1499
1500
1501
1502
1503
1504
1505
1506
1507
1508
1509
1510
1511
1512
1513
1514
1515
1516
1517
1518
1519

1520
1521
1522
1523
1524
1525
1526
1527
1528
1529
1530
1531
1532
1533
1534
1535
1536
1537
1538
1539
1540 | ; AXE134 Serial 20x4 OLED using PICAXE-18M2*
1541 | ; Emulates basic serial operation of the popular AXE033 module
1542 | ; CPS, May 2011
1543 | ; JB, Jan 2012
1544
1545 #picaxe 18M2
1546
1547
1548 | ; Supported Commands
1549 | ; 0-7, 8-15 | CGRAM characters
1550 | ; 16-252 | normal ASCII characters, according to selected character map table
1551 | ; 253, X | display 12 character pre-saved message from EEPROM memory, X can be 0-11
1552 | ; 254, X | OLED command, X can be 0 to 255
1553 | ; 255, X | control outputs C.2, C.1, C.0 (via lower 3 bits of X)
1554
1555 | #define use_welcome | ; display the welcome message upon power up
1556
1557 | symbol baud = N2400_16 | ; Serial baud rate 2400,N,8,1. Note main program runs at 16MHz
1558
1559 | symbol spare0 | = C.0 ; spare output 0
1560 | symbol spare1 | = C.1 ; spare output 1
1561 | symbol spare2 | = C.2 ; spare output 2
1562 | symbol RX | = C.5 | ; serial receive pin
1563 | symbol enable | = C.6 | ; OLED enable
1564 | symbol rs | = C.7 | ; OLED RS
1565
1566 ; OLED data pins are on B.0 to B.7
1567
1568 | ; Store the 20 character user defined messages in EEPROM data memory
1569 | ; First two messages are optionally used as welcome message
1570
1571 ; Please remember 4 line displays always use the strange 1-3-2-4 line layout. 1572
1573 | EEPROM 00, (" PLOS starting up ") | ; store msg 0 in the EEPROM memory
1574 | EEPROM 20, ("designed, built, and") | ; store msg 1 in the EEPROM memory
1575 | EEPROM 40, (" programmed by ") | ; store msg 2 in the EEPROM memory
1576 | EEPROM 60, (" Patrick Leiser ") | ; store msg 3 in the EEPROM memory
1577 | EEPROM 80, ("This is msg 4 | ") | ; store msg 4 in the EEPROM memory
1578 | EEPROM 100, ("This is msg 5 | ") | ; store msg 5 in the EEPROM memory
1579 | EEPROM 120, ("This is msg 6 | ") | ; store msg 6 in the EEPROM memory
1580 | EEPROM 140, ("This is msg 7 | ") | ; store msg 7 in the EEPROM memory

1581 | EEPROM 160, ("This is msg 8 | ") | ; store msg 8 in the EEPROM memory
1582 | EEPROM 180, ("This is msg 9 | ") | ; store msg 9 in the EEPROM memory
1583 | EEPROM 200, ("This is msg 10 | ") | ; store msg 10 in the EEPROM memory
1584 | EEPROM 220, ("This is msg 11 | ") | ; store msg 11 in the EEPROM memory
1585
1586 | ;initialise OLED
1587 | init:
1588 | gosub OLED_init | ; initialise OLED
1589
1590 | ; display welcome message if desired
1591 | #ifdef use_welcome
1592 | let b1 = 0 | ; message 0 on top line
1593 | gosub msg | ; do it
1594
1595 | low rs | ; command mode
1596 | let pinsB = 192 | ; move to line 2, instruction 192
1597 | pulsout enable,1 | ; pulse the enable pin to send data.
1598 | high rs | ; character mode again
1599
1600 | let b1 = 1 | ; message 1 on bottom line
1601 | gosub msg | ; do it
1602
1603
1604 | low rs | ; command mode
1605 | let pinsB = 148 | ; move to line 2, instruction 192
1606 | pulsout enable,1 | ; pulse the enable pin to send data.
1607 | high rs | ; character mode again
1608
1609 | let b1 = 2 | ; message 2 on bottom line
1610 | gosub msg | ; do it
1611 | low rs | ; command mode
1612 | let pinsB = 212 | ; move to line 2, instruction 192
1613 | pulsout enable,1 | ; pulse the enable pin to send data.
1614 | high rs | ; character mode again
1615
1616 | let b1 = 3 | ; message 3 on bottom line
1617 | gosub msg | ; do it
1618 | #endif
1619
1620 ; main program loop, runs at 16MHz 1621
1622 main:
1623
1624 | serin RX,baud,b1 | | ; wait for the next byte
1625
1626 | ; NB keep character mode test as first item in this list to optimise speed
1627 | if b1 < 253 then
1628 | let pinsB = b1 | | ; output the data
1629 | pulsout enable,1 | ; pulse the enable pin to send data.
1630 | goto main | | ; quickly loop back to top
1631 | else if b1 = 254 then
1632 | low rs | | ; change to command mode for next character
1633 | serin RX,baud,b1 | | ; wait for the command byte
1634 | let pinsB = b1 | | ; output the data
1635 | pulsout enable,1 | ; pulse the enable pin to send data.
1636 | high rs | ; back to character mode
1637 | goto main | | ; quickly loop back to top
1638 | else if b1 = 253 then
1639 | serin RX,baud,b1 | | ; wait for the next byte
1640 | gosub msg | | ; do the 16 character message
1641 | goto main | | ; back to top

1642 | else ; must be 255
1643 | serin RX,baud,b1 | ; wait for the next byte
1644 | let pinsC = b1 & %00000111 | %10000000
1645 | ; output the data on C.0 to C.1, keep RS high
1646 | goto main | ; back to top
1647 | end if
1648
1649
1650 | ; power on OLED initialisation sub routine
1651 | OLED_init:
1652 | let dirsC = %11000111 | ; PortC 0,1,2,6,7 all outputs
1653 | let dirsB = %11111111 | ; PortB all outputs
1654
1655 | ; Winstar OLED Module Initialisation
1656 | ; according to WS0010 datasheet (8 bit mode)
1657
1658 | pause 500 | ; Power stabilistation = 500ms
1659
1660 | ; Function set - select only one of these 4 character table modes
1661 | ;let pinsB = %00111000 | ; 8 bit, 2 line, 5x8 , English_Japanese table
1662 | let pinsB = %00111001 | ; 8 bit, 2 line, 5x8 , Western_European table1
1663 | ;let pinsB = %00111010 | ; 8 bit, 2 line, 5x8 , English_Russian table
1664 | ;let pinsB = %00111011 | ; 8 bit, 2 line, 5x8 , Western_European table2
1665
1666 | pulsout enable,1 | ;
1667
1668 | let pinsB = %00001100 | ; Display on, no cursor, no blink
1669 | pulsout enable,1
1670
1671 | let pinsB = %00000001 | ; Display Clear
1672 | pulsout enable,1
1673 | pause 7 | ; Allow 6.2ms to clear display
1674
1675 | setfreq m16 | ; now change to 16Mhz
1676
1677 | let pinsB = %00000010 | ; Return Home
1678 | pulsout enable,1
1679
1680 | let pinsB = %00000110 | ; Entry Mode, ID=1, SH=0
1681 | pulsout enable, 1
1682
1683 | high rs | ; Leave in character mode
1684 | return
1685
1686
1687 | ; display message from EEPROM sub routine
1688 | ; message number 0-11 must be in b1 when called
1689 | ; uses (alters) b1, b2, b3, b4
1690 | msg:
1691 | let b2 = b1 // 12 * 20 | ; EEPROM start address is 0 to 11 multiplied by 20
1692 | let b3 = b2 + 20 - 1 | ; end address is start address + (20 - 1)
1693 | for b4 = b2 to b3 | ; for 20 times
1694 | read b4,b1 | ; read next character from EEPROM data memory into b1
1695 | let pinsB = b1 | ; output the data
1696 | pulsout enable,1 | ; pulse the enable pin to send data.
1697 | next b4 | ; next loop
1698 | return
1699
1700
'* note that this code came with the AXE134G OLED display I bought, I modified it to customise the startup message

1701

1702 | '* the original code can be found at http://www.picaxe.com/downloads/axe134y.bas.txt
1703 | '* the other two programs (the main program and the keyboard program) are original and writen by me
1704 | '*they can be found at http://patrickleiser.weebly.com/picaxe-computer.html

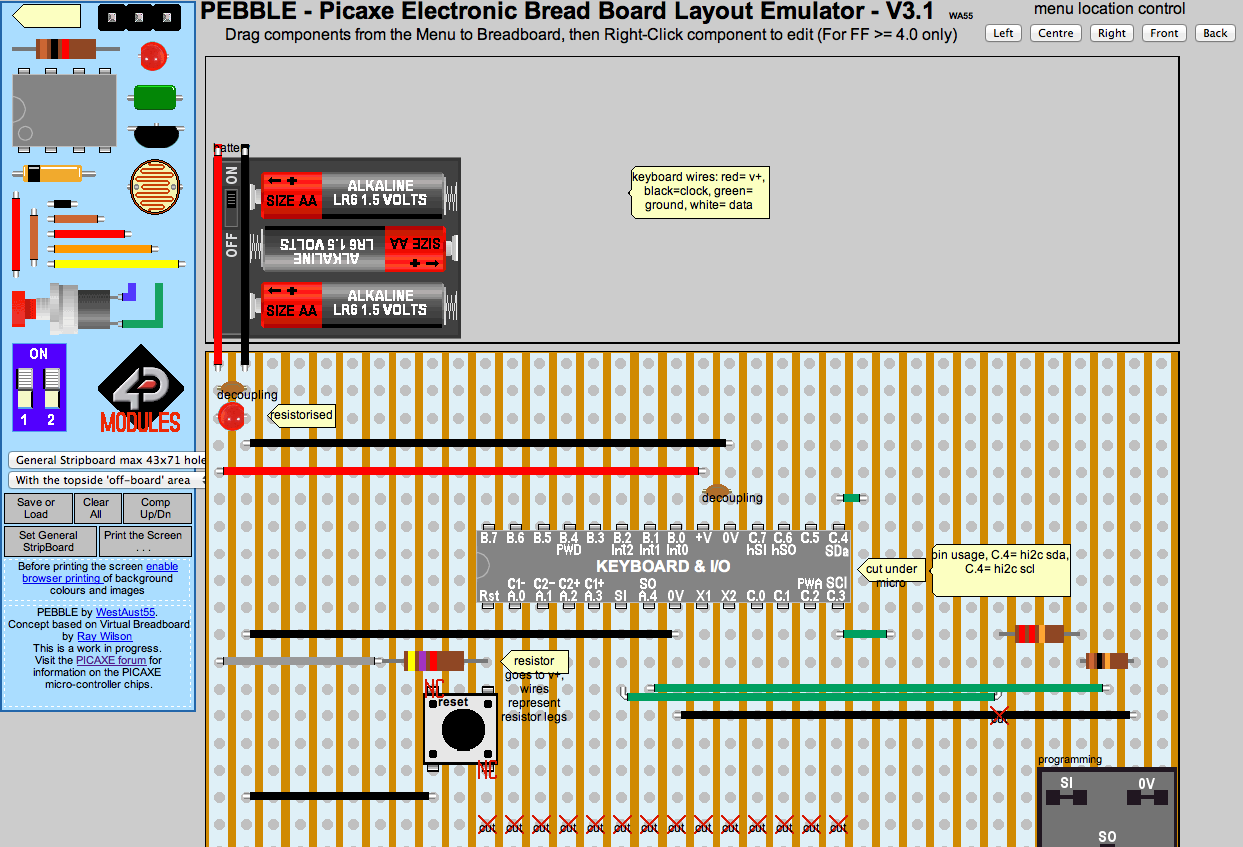
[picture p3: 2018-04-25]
laptop project/report/screenshots/Screen Shot 2013-03-06 at 7.35.21 AM.png

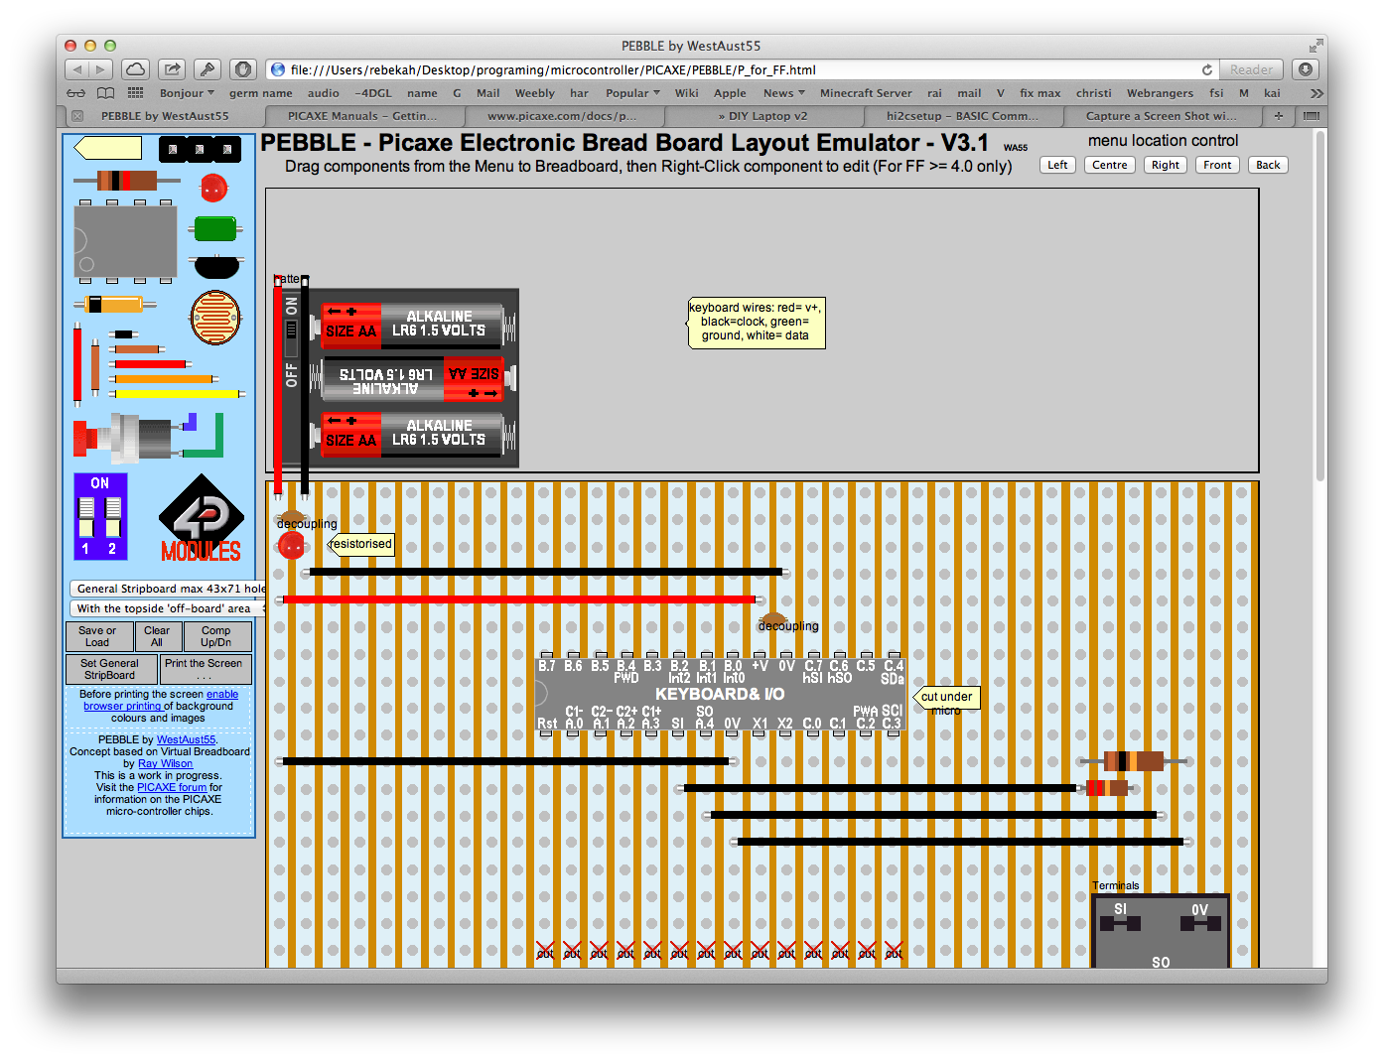
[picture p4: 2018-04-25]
laptop project/report/screenshots/Screen Shot 2012-12-24 at 2.32.42 PM.png

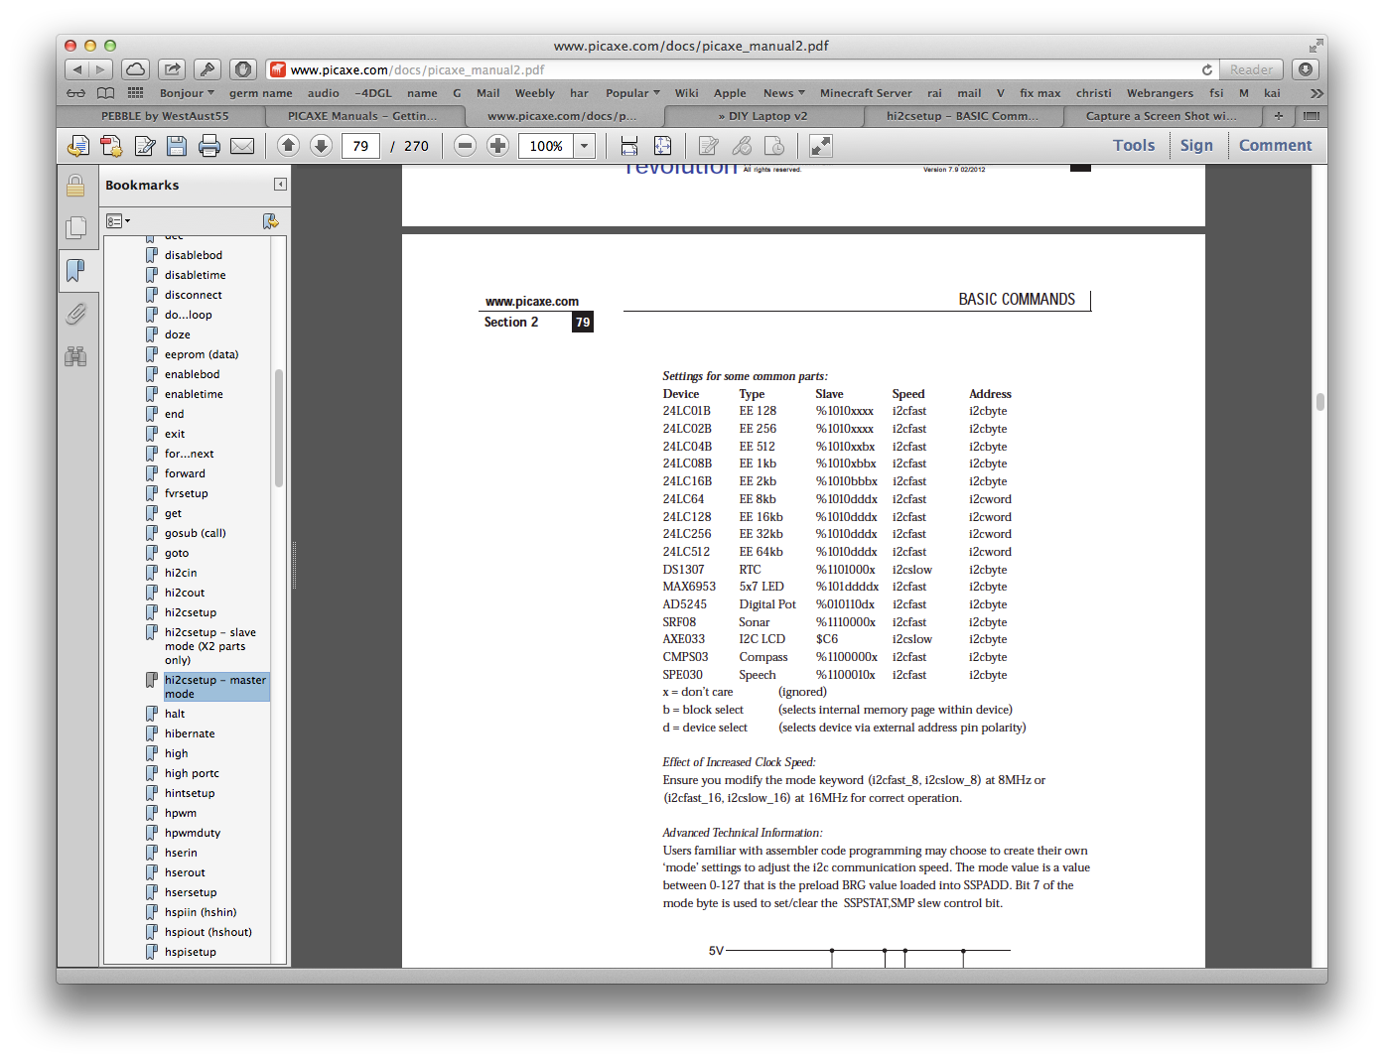
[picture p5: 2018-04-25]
laptop project/report/screenshots/Screen Shot 2012-12-24 at 2.33.34 PM.png

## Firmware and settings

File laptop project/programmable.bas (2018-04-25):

'picaxe laptop demo slot 1      'by Patrick Leiser
#picaxe 28x2
#slot 1

symbol screenspeed=N2400_8       'N2400 at 8 MHz
symbol i2cspeed=i2cfast_8            'i2c 400khz at 8 MHz
'system variables
symbol screenlevel=bit0        'unused scrolling function
symbol tempbit1 =bit1          'temporary bit 1
symbol tempbit2=bit2            'tempoary bit 2
symbol loopcount=b11           ' number of loops in for...next loops
symbol menupage=b21          'which page of menu you are on
'i2c constants
symbol alfat=%10100100       'sd card reader
symbol keyboard=%01010100       'keyboard reading PICAXE 28X2
'keyboard variables
symbol keycheck = b4              'will be one when data is valid, otherwise 0 or 255
symbol keyraw =b5                  'data direcly from keyboard
symbol keyascii = b6                'data from keyboard converted to ASCII
symbol keynum = b7                ' value of number keys 0-9
'wordedit variables
symbol cursorrow = b8             'part of row in wordedit
symbol cursorcol = b9              'part of colum in wordedit
symbol cursorpos = b10           'cursor position for OLED
'
symbol temp1=b14                    'temporary byte (8 bits)1
symbol temp2=b15                    'tempoaray byte 2
symbol tempw1=w7                   'tempoary word (16 bits) 1  (overlaps temp1 and temp2)
symbol temp3=b16                    'tempoary byte 3
symbol temp4=b17                    'tempoary byte 4
symbol tempw2=w8                  'tempoary word 2      (overlaps temp3 and temp4
symbol temp5=b18                   'tempoary byte 5
symbol temp6=b19                    'tempoary byte 6
symbol tempw3=w9                'tempoary word 3      (overlaps temp5 and temp6
symbol charremove=b20             'amount of sd card data to remove eg !00
'symbol charremove1=b24         'single character to remove eg !
symbol pointertrack=w11       'track pointer read loops
symbol first=b24
symbol second=b25

symbol commandpos=b26
symbol com1=b27
symbol com2=b28
symbol com3=b29
symbol prgtempw1=w15'b30&b31
symbol prgtempb1=b32
symbol prgtempb2=b33

main:
menu:             'menu
serout C.1,screenspeed, (254,128)
serout C.1, screenspeed, (254,1)
pause 30
serout C.1,screenspeed, ("1 write program")
serout C.1,screenspeed, (254,192,"2 run program")
serout C.1,screenspeed, (254,148,"3 LED")
serout C.1,screenspeed, (254,212,"4 run program V2")
gosub getakey
branch keynum,(menu,wordeditsetup,sdreadsetup,runled,programstart)'calculatorsetup,countdowntimer)

if keyraw= 118 or keyraw=108 then menu
goto menu



wordeditsetup:
serout C.1, screenspeed, (254,14,254,128,254,1)    'cursor on, top of display, clear display
pause 30
cursorrow=0         'top of display
cursorcol=0          'top of display
wordedit:
	gosub getakey       'get a key from keyboard
		
	select case keyraw     'select raw key value
	case 118                        'esc
		goto menu
	case 108              'home
		cursorrow=255
		cursorcol=0
	case 90                                  'enter
		cursorrow = 21
		@ptrinc=cr
		@ptrinc=lf
	case 102                                 'backspace
		if cursorrow = 0 then
			dec cursorcol
			cursorrow = 20
		endif
		cursorrow=cursorrow-1
		gosub position
			cursorrow=cursorrow-1
		serout C.1,screenspeed, (" ")
	case 13                                       'tab
		cursorrow=cursorrow+2
		serout C.1, screenspeed, ("  ")
		@bptrinc=9         'tab
		@ptrinc=9            'tab
		@bptrinc=0         'null
		@bptr=0              'null
	case 107                                  'left arrow
		if cursorrow = 0 then
			dec cursorcol
			cursorrow = 20
		endif
		cursorrow=cursorrow - 2
	case 116                                  'right arrow
	case 114                                  'down arrow
		inc cursorcol
		dec cursorrow
	case 117                                  'up arrow
		dec cursorcol
		dec cursorrow
	case 124
		serout C.1, screenspeed, (254,128,"print screen")
		goto printscreen
	else
		serout C.1,screenspeed, (keyascii)
		@bptr=keyascii                 'store contents of the screen for ability to save
		@ptrinc=keyascii              'store contents of the screen for abbility to save (work in progress)
	endselect
	
	inc cursorrow
	gosub position
		goto wordedit
position:              'update position of cursor
	if cursorrow >19 then
		inc cursorcol
		cursorrow=0
	endif
		select case cursorcol
		case 1
			cursorpos=192
			'serout C.1, N2400, (254, 192)
			'serout C.1, N2400, ("ln 1")
		case 2
			cursorpos=148
			'serout C.1, N2400, (254, 148)
			'serout C.1,N2400,("ln 2")
		case 3
			cursorpos=212
			'serout C.1,N2400, (254,212) 
			'serout C.1, n2400,("ln 4")
		else
			cursorpos=128
			'serout C.1,N2400,(254,128)
			'serout C.1,N2400,("ln 0")
			cursorcol=0
		endselect
		cursorpos = cursorrow+cursorpos
		bptr=cursorpos
		serout C.1, screenspeed, (254,cursorpos)
		return
	goto wordedit
	
	
printscreen:  ' save the contents of the screen to SD card
hi2cout [alfat],("O 1A>M:\\programs",92)   '92=\      \\=\
serout C.1, screenspeed, (254,128,"name (not full path)")
gosub sdout
pointertrack= ptr

first = pointertrack / 16 + "0"          '4 msb plus ascii "0"
If first > "9" Then                             'if more than "9"
  first = first + 7                              'add seven   (starting "A","B",etc
EndIf

second = pointertrack & $0F + "0"
If second > "9" Then
  second = second + 7
EndIf
hi2cout ("W 1>",first,second,lf)  'write handle 1, pointertrack characters, 
sertxd (#pointertrack)
hi2cin (b12,b12,b12,b12)
for ptr=0 to pointertrack
	
	
	hi2cout (@ptr)
	sertxd (@ptr,#ptr)
	for loopcount = 0 to 14
	hi2cin (b12)
	next loopcount
next ptr
'for bptr=128 to 147         'line 1
'	hi2cout ("W 1>1",lf)  'write handle 1, one character, 
'	hi2cin (b12)
'	serout C.1,screenspeed, (b12) 
'	hi2cin (b12)
'	serout C.1,screenspeed, (b12)
'	hi2cin (b12)
'	serout C.1,screenspeed, (b12)
'	hi2cin (b12)
'	serout C.1,screenspeed, (b12)
'	hi2cout(@bptr)
'	for loopcount = 0 to 14
'	hi2cin (b12)
'	next loopcount
'next bptr
'for bptr=192 to 211       'line 2
'	hi2cout ("W 1>1",lf)
'	hi2cin (b12,b12,b12,b12)
'	hi2cout(@bptr)
'	for loopcount = 0 to 14
'	hi2cin (b12)
'	next loopcount
'next bptr
'for bptr=148 to 167         'line 3
'	hi2cout ("W 1>1",lf)
'	hi2cin (b12,b12,b12,b12)
'	hi2cout(@bptr)
'	for loopcount = 0 to 14
'	hi2cin (b12)
'	next loopcount
'next bptr
'for bptr=212 to 241         'line 4
''	hi2cout ("W 1>1",lf)
'	hi2cin (b12,b12,b12,b12)
'	hi2cout(@bptr)
'	for loopcount = 0 to 14
'	hi2cin (b12)
'	next loopcount
'next bptr

hi2cout ("C 1",lf)
hi2cout ("C 1",lf)
hi2cin (b12,b12,b12,b12)

serout C.1, screenspeed, (254,128,"complete")
gosub getakey
goto wordeditsetup

runled:
pause 30
hi2cout [alfat],("O 0R>M:\\programs\\led.txt",lf)   '\\=\
goto presdread
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

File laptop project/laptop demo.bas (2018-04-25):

'picaxe laptop demo program slot 0        'by Patrick Leiser
'© Patrick Leiser Feel free to use this program, but leave this copyright message intact.
#picaxe 28x2
#slot 0
#revision 4
'pinout
'                       _________
'              reset | rst  B.7 |  LED (red)
'                       | A.0  B.6|  Speakers
'                       | A.1  B.5|
'                       | A.2  B.4|
'                       | A.3  B.3|
'              serin  |serin B.2|  keyboard wakeup (currently unused)
'            serout |A.4   B.1|
'                  0V | 0V   B.0|
'                       | res   +V|    +5V
'                       | res  0V |       0V
'  SD card busy | C.0  C.7|
'   OLED serout | C.1  C.6|
'                       | C.2  C.5|
'               hi2c | C.3  C.4|  hi2c (keyboard and SD card)
'                       _________
#define 8mhz       'clock frequency is 8mhz
'#define 16mhz      'too fast for display, overclock display to 32 Mhz?
#ifdef 8mhz
setfreq m8      'set clock frequency to 8MHz
symbol screenspeed=N2400_8       'N2400 at 8 MHz
symbol i2cspeed=i2cfast_8            'i2c 400khz at 8 MHz
#endif
#ifdef 16mhz
setfreq m16     'set clock frequency to 16 MHz     
symbol screenspeed=N2400_16        'N2400 at 16 MHz
symbol i2cspeed=i2cfast_16               'i2c 400khz at 16 MHz
#endif
'i2c constants
symbol alfat=%10100100       'sd card reader
symbol keyboard=%01010100       'keyboard reading PICAXE 28X2
'system variables
symbol screenlevel=bit0        'unused scrolling function
symbol tempbit1 =bit1          'temporary bit 1
symbol tempbit2=bit2            'tempoary bit 2
symbol loopcount=b11           ' number of loops in for...next loops
symbol menupage=b21          'which page of menu you are on
'keyboard variables
symbol keycheck = b4              'will be one when data is valid, otherwise 0 or 255
symbol keyraw =b5                  'data direcly from keyboard
symbol keyascii = b6                'data from keyboard converted to ASCII
symbol keynum = b7                ' value of number keys 0-9
'wordedit variables
symbol cursorrow = b8             'part of row in wordedit
symbol cursorcol = b9              'part of colum in wordedit
symbol cursorpos = b10           'cursor position for OLED
'
symbol temp1=b14                    'temporary byte (8 bits)1
symbol temp2=b15                    'tempoaray byte 2
symbol tempw1=w7                   'tempoary word (16 bits) 1  (overlaps temp1 and temp2)
symbol temp3=b16                    'tempoary byte 3
symbol temp4=b17                    'tempoary byte 4
symbol tempw2=w8                  'tempoary word 2      (overlaps temp3 and temp4
symbol temp5=b18                   'tempoary byte 5
symbol temp6=b19                    'tempoary byte 6
symbol tempw3=w9                'tempoary word 3      (overlaps temp5 and temp6
symbol charremove=b20             'amount of sd card data to remove eg !00
'symbol charremove1=b24         'single character to remove eg !
symbol pointertrack=w11       'track pointer read loops
symbol first=b24
symbol second=b25
'game variables
'symbol guesscount = b11
'symbol hitcount = b0
'symbol gamerandom = b12
'symbol gamerandom2 =b13
'symbol gamerandom3 =b14
'symbol gamerandom4 =b15
'symbol gamerandom5 =b16
'symbol gamerandom6 =b17
'symbol gamerandom7 =b18
'symbol gamerandom8 =b19


'math variables
'symbol math1=w3 'b4/b5
'symbol mathone=w3 'b4/b5
'symbol math2=w4 'b6/b7
'symbol mathtwo=w4 'b6/b7
'symbol mathresult=w6'b8/b9
'startup


if pinC.4=0 then                           ' if i2c read/write in progress
	for loopcount = 0 to 15
		toggle C.3                       'clear i2c bus read/write
		pause 30
		if pinC.4=1 then exit
	next loopcount
endif
hi2csetup i2cmaster,alfat,i2cspeed,i2cbyte     'setup i2c comunication for SD card reader
'pause 200
hi2cout ("I M:",lf)     'initalise sd card

setup:
hi2cin (b12)
if b12=255 then setup2
if b12 <> "!" then setup
hi2cin (b12,b12,b12)

hi2cout ("I M:",lf)
setup2:
#ifdef 8mhz
'pause 600
tune B.6,4,($40,$42,$44,$45,$47,$02,$49)      'startup chime
#endif
#ifdef 16mhz
tune B.6,8,($40,$42,$44,$45,$47,$02,$49)      'startup chime
#endif
serout C.1, screenspeed, (254,128,254,1)'clear display

'read voltage
'CalibAdc10 tempw1      'read voltage of internal fixed voltage reference
gosub getvolts
'tempw1 = 10476 / tempw1      'convert to volts
if tempw1<38 then
	gosub powerdisplay
	sound B.6, (50,50,100,50)
	gosub getakey
endif
#ifdef 8mhz
pause 30               'pause 30  ms
#endif
#ifdef 16mhz
pause 70
#endif

'''''''''''''''''''''''''''''''''''''''''''''''''''''''''''''''''''''''''''''''''''''''''''''''''''''''''''''''
'menus
main:
'clearvar:
'for bptr=5 to 255
'	@bptr=0
'next bptr
menu:        'main menu
serout C.1,screenspeed, (254,128,254,1)     'clear display
	pause 30
select case menupage    'select page
case 0    'first page
	serout C.1,screenspeed, ("1 Utilities",254,192,"2 Tests",254,148,"3 SD card",254,212,"4 run",180)    'menu display
	'serout C.1,N2400,(254,192,"2 Tests")

	'serout C.1,N2400,(254,148,"3 SD card")
	'serout C.1,N2400,(254,148,"3 games")
	'serout C.1,N2400, (254,212,"4 favorites  ",180)
	'serout C.1,N2400, (254,212,"4 other")
	'serout C.1,N2400,(254,212,"4 calculator")
case 1    '2nd page
	serout C.1,screenspeed,("5 other")
else 
	menupage=0
	goto menu
endselect
gosub getakey
branch keynum, (menu,utilitymenu, testmenu,gamemenu,favoritesmenu,othermenu)          'go to menu item selected by key on keyboard
'if keynum = 10 then
	select case keyraw     'shortcut keys
	case 29         'w
		goto wordeditsetup
	case 45          'r
		goto sdreadsetup
	case 75          'l
		goto sdinitalizelist
	case 33          'c
		goto calculatorsetup
	endselect
'endif
if keyraw=90 or keyraw= 114 then
	inc menupage
elseif keyraw=102 or keyraw=117 then
	dec menupage
endif
goto menu

utilitymenu:             'utility menu
serout C.1,screenspeed, (254,128)
serout C.1, screenspeed, (254,1)
pause 30
serout C.1,screenspeed, ("1 Wordedit")
serout C.1,screenspeed, (254,192,"2 calculator")
serout C.1,screenspeed, (254,148,"3 Timer")
'serout C.1,N2400,(254,148,"3 ")

'serout C.1,N2400,(254,212,"4 ")

gosub getakey
branch keynum,(menu,wordeditsetup,calculatorsetup,countdowntimer)

if keyraw= 118 or keyraw=108 then menu
goto utilitymenu


testmenu:            'test menu
serout C.1,screenspeed, (254,128)
serout C.1, screenspeed, (254,1)
pause 30
serout C.1,screenspeed, ("1 list characters")
serout C.1,screenspeed,(254,192,"2 Keyboard to screen")
serout C.1,screenspeed,(254,148,"3 read power supply")
serout C.1,screenspeed,(254,212,"4 System info")
'serout C.1,N2400, (254,212,"4 SD card read")
'serout C.1,N2400,(254,212,"4 calculator")

gosub getakey
branch keynum,(menu,listcharacters,keyboardtoscreen,readpower,sysinfo)',gettime)

if keyraw=118 or keyraw=108 then menu
goto testmenu
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
